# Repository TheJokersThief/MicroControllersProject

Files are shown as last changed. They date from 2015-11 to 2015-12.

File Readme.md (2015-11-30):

# Burglar Alarm Arduino Project
**Task:** Build a burglar alarm — The task for the project was to build a device, using an arduino, that could monitor several different types of zones, log alarm trips and allow for user and admin interaction via an LCD. When an alarm condition is met, a buzzer or LED will go off indicating as such.

## Authors
1. **Evan Smith**
	* [iamevan.me](http://iamevan.me)
	* [@TheJokersThief](http://twitter.com/thejokersthief)
	* [evan.netsoc.co](http://evan.netsoc.co)
2. **Colm Cahalane**
	* [colm.cf](http://colm.cf)
	* [@1108oo](http://twitter.com/1108oo)
	* [colm.netsoc.co](http://colm.netsoc.co)

## Limitations
* 512MB permanent memory for logging and settings storage 
* Only the admin is allowed to change settings
 	
## Features
* The date and time is displayed by default on the LCD 
* There are 4 zones hooked up to the alarm:
	1. Entry/Exit: This is linked to the front door. When tripped, it allows a certain amount of time to disable the alarm before it starts ringing.
	2. Digital: This would be linked to sensors attached to the windows or other vulnerable aspects of the house. When contact is broken, it sets off the alarm. E.G. If a burglar broke in by prying open the window.
	3. Analog: Connected to analog sensors such as a thermometer for detecting heat or variable motion sensors. This is tripped after the sensor signal breaches a certain threshold.
	4. Continuous Monitoring: This alarm is tripped when the signal transitions from high to low, used primarily to ensure no tampering occurs with the burglar alarm.
* A number of zones are programmable and administrators can set a variety of options like: – User password
	* Admin password
	* Do-not-disturb times for the entry/exit zone – Digital zone trip condition
* Whenever a zone is tripped, the event is logged to permanent storage
* Settings, logs, passwords and alarm configuration can be done with an Infra Red Remote

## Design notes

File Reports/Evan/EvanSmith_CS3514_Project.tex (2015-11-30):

%%% Template originaly created by Karol Kozioł (mail@karol-koziol.net) and modified for ShareLaTeX use

\documentclass[a4paper,11pt]{article}

\usepackage[T1]{fontenc}
\usepackage[utf8]{inputenc}
\usepackage{graphicx}
\usepackage{xcolor}

\usepackage{amsmath,amssymb,amsthm,textcomp}
\usepackage{enumerate}
\usepackage{multicol}
\usepackage{tikz}
\usepackage{hyperref}

\usepackage{geometry}
\geometry{total={210mm,297mm},
left=25mm,right=25mm,%
bindingoffset=0mm, top=20mm,bottom=20mm}

\linespread{1.3}

\newcommand{\linia}{\rule{\linewidth}{0.5pt}}

% custom theorems if needed
\newtheoremstyle{mytheor}
    {1ex}{1ex}{\normalfont}{0pt}{\scshape}{.}{1ex}
    {{\thmname{#1 }}{\thmnumber{#2}}{\thmnote{ (#3)}}}

\theoremstyle{mytheor}
\newtheorem{defi}{Definition}

% % my own titles
% \makeatletter
% \renewcommand{\maketitle}{
% \begin{center}
% \vspace{2ex}
% {\huge \textsc{\@title}}
% \vspace{1ex}
% \\
% \linia\\
% \@author \hfill \@date
% \vspace{4ex}
% \end{center}
% }
% \makeatother
% %%%

% custom footers and headers
\usepackage{fancyhdr}
\pagestyle{fancy}
\lhead{}
\chead{}
\rhead{}
\lfoot{CS3514 - Burglar Alarm Project}
\cfoot{}
\rfoot{Page \thepage}
\renewcommand{\headrulewidth}{0pt}
\renewcommand{\footrulewidth}{0pt}
%

% code listing settings
\usepackage{listings}
\lstset{
    language=c,
    basicstyle=\ttfamily\small,
    aboveskip={1.0\baselineskip},
    belowskip={1.0\baselineskip},
    columns=fixed,
    extendedchars=true,
    breaklines=true,
    tabsize=4,
    prebreak=\raisebox{0ex}[0ex][0ex]{\ensuremath{\hookleftarrow}},
    frame=leftline,
    showtabs=false,
    showspaces=false,
    showstringspaces=false,
    keywordstyle=\color[rgb]{0.627,0.126,0.941},
    commentstyle=\color[rgb]{0.133,0.545,0.133},
    stringstyle=\color[rgb]{0.60,0,0},
    numbers=left,
    numberstyle=\small,
    stepnumber=1,
    numbersep=10pt,
    captionpos=t,
    escapeinside={},
    morekeywords={sudo, su, apt-get},
    prebreak= \space,
    postbreak   = \space
}

\hypersetup{%
  colorlinks=true,% hyperlinks will be coloured
  linkcolor=black,% hyperlink text will be green
  linkbordercolor=red,% hyperlink border will be red
}

\usepackage{parskip}

% COLOURS %
\definecolor{inlinebackground}{RGB}{252, 252, 252}

% COMMANDS %
\newcommand{\inlinecode}[1]{\colorbox{inlinebackground}{\lstinline[basicstyle=\ttfamily\color{black}]|#1|}}

%%%----------%%%----------%%%----------%%%----------%%%

\begin{document}

\title{CS3514 - Burglar Alarm Project}

\author{Evan Smith <113300626> and Colm Cahalane}

\date{19/11/2015}

\maketitle

\tableofcontents
\newpage

\section{Introduction}
\textbf{Build a burglar alarm }--- The task for the project was to build a device, using an arduino, that could monitor several different types of zones, log alarm trips and allow for user and admin interaction via an LCD. When an alarm condition is met, a buzzer or LED will go off indicating as such.

\section{Requirements / Analysis / Design }
\subsection{Limitations}
\begin{itemize}
    \item 512MB permanent memory for logging and settings storage
    \item Only the admin is allowed to change settings
\end{itemize}

\subsection{Features}
\begin{itemize}
    \item The date and time is displayed by default on the LCD 
    \item There are 4 zones hooked up to the alarm:
    \begin{enumerate}
        \item \textbf{Entry/Exit:} This is linked to the front door. When tripped, it allows a certain amount of time to disable the alarm before it starts ringing.
        \item \textbf{Digital:} This would be linked to sensors attached to the windows or other vulnerable aspects of the house. When contact is broken, it sets off the alarm. E.G. If a burglar broke in by prying open the window.
        \item \textbf{Analog:} Connected to analog sensors such as a thermometer for detecting heat or variable motion sensors. This is tripped after the sensor signal breaches a certain threshold.
        \item \textbf{Continuous Monitoring:} This alarm is tripped when the signal transitions from high to low, used primarily to ensure no tampering occurs with the burglar alarm.
    \end{enumerate}
    \item A number of zones are programmable and administrators can set a variety of options like:
    \begin{itemize}
        \item User password
        \item Admin password
        \item Do-not-disturb times for the entry/exit zone
        \item Digital zone trip condition
    \end{itemize}
    \item Whenever a zone is tripped, the event is logged to permanent storage
    \item Settings, logs, passwords and alarm configuration can be done with an Infra Red Remote
\end{itemize}

\newpage
\section{Implementation}

\subsection{Flow chart}
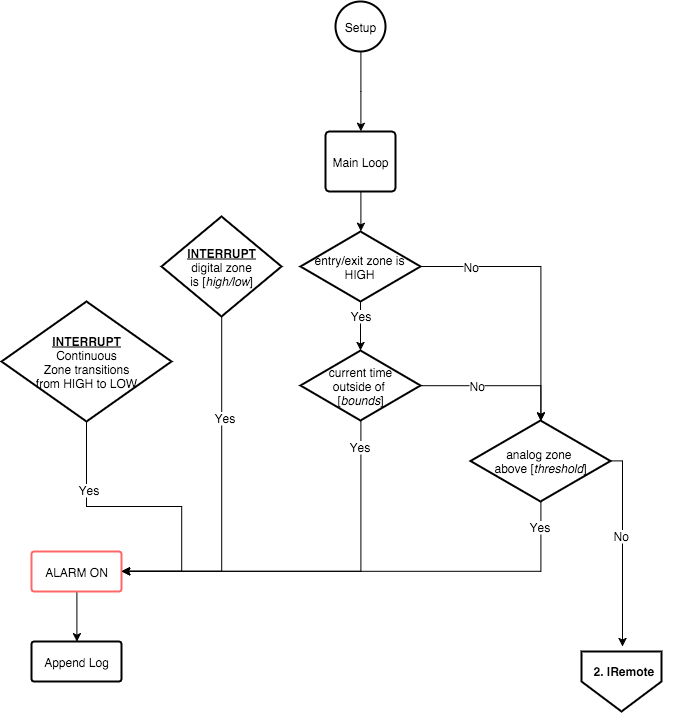
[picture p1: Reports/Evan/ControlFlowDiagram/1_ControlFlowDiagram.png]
\makebox[\textwidth]{}
\newpage
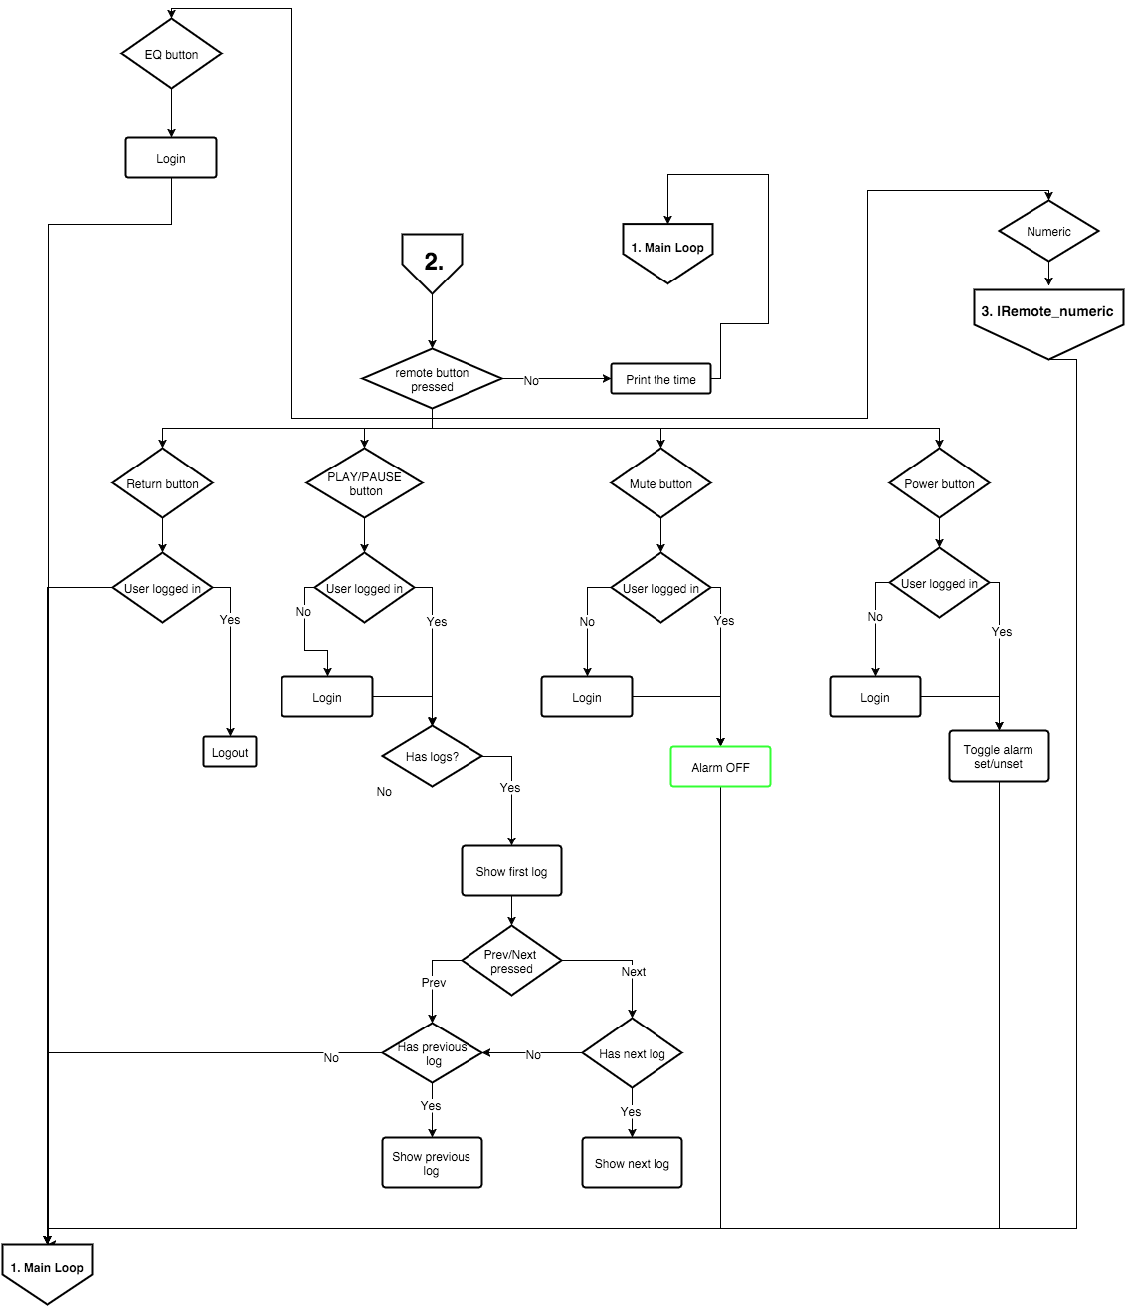
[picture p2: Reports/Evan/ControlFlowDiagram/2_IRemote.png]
\makebox[\textwidth]{}
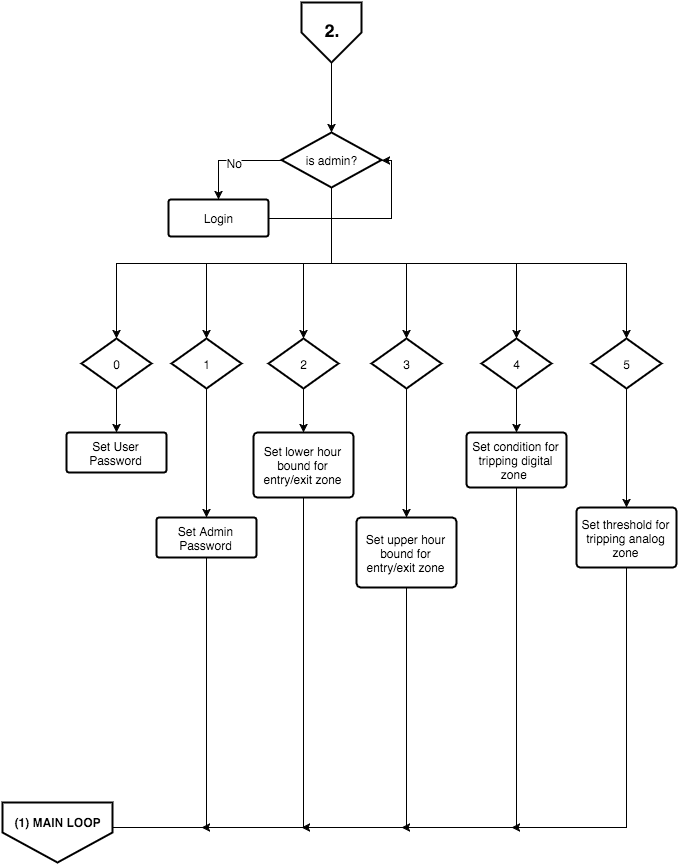
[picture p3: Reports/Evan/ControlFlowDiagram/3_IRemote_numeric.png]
\makebox[\textwidth]{}

\subsection{Circuit Diagram}
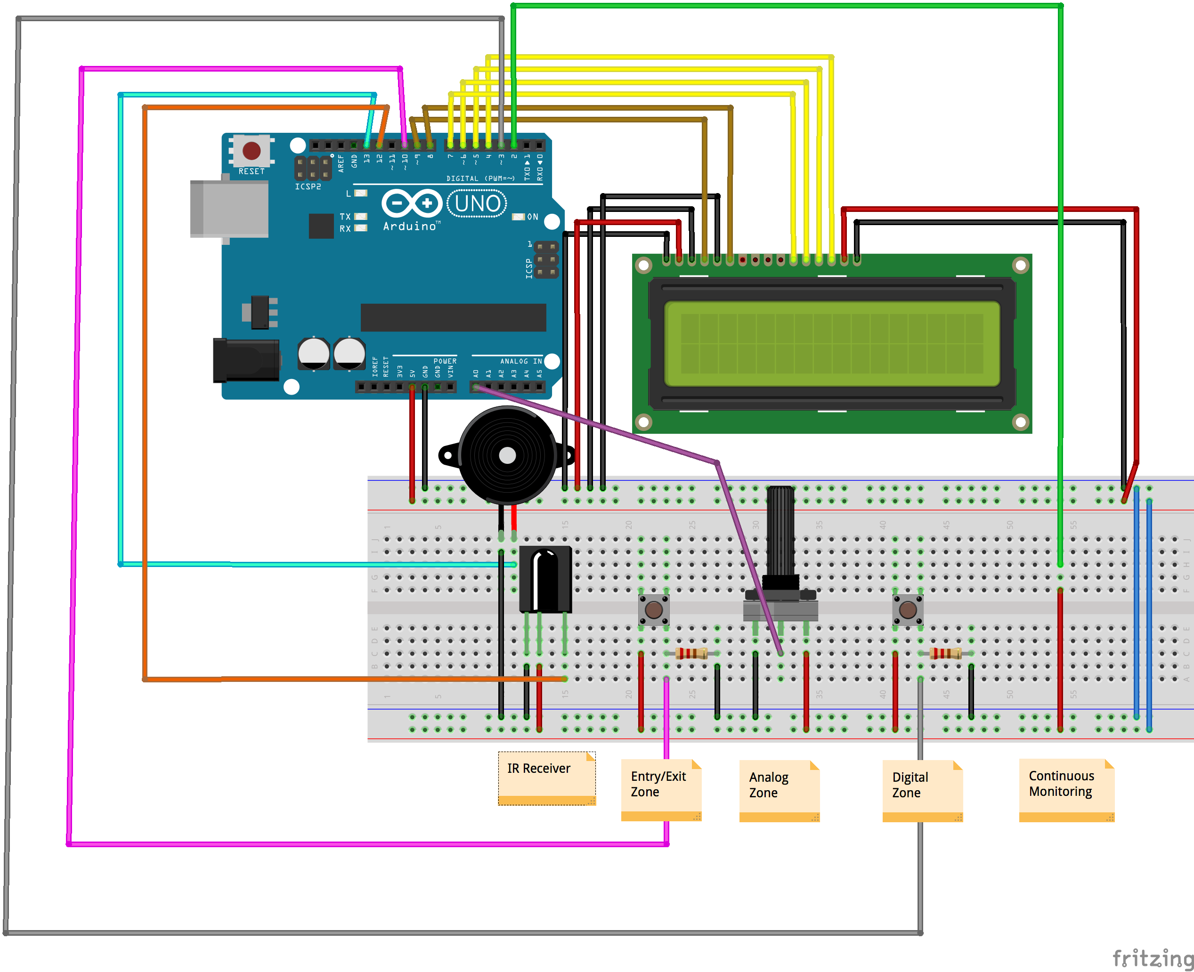
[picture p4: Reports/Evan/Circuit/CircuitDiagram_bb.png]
\makebox[\textwidth]{}

\subsection{Coding decisions}

\subsubsection{Global Variables}
We decided to have five global variables:

\begin{lstlisting}
// initialize the library with the numbers of the interface pins
LiquidCrystal lcd(9, 8, 7, 6, 5, 4);

// Used to check if current user is an admin
unsigned short is_admin = 0;

// 0 is disabled ; 1 is enabled
unsigned short alarm_set = 0;

// 0 alarm is idle ; 1 alarm is ringing
// Volatile because needed in interrupts
volatile unsigned short alarm_active = 0;

// 0 not logged in ; 1 logged in 
unsigned short is_user_logged_in = 0;
\end{lstlisting}

All of these variables are used extensively within other functions for manipulation of the components overall, which is the reason they've been globalised.

\subsubsection{Debouncing IR}

At many points in our code, we add a delay after receiving a numeric signal from the IR Remote in order to prevent extraneous zeroes corrupting the intended number.

\subsubsection{Default Settings on First Time}

When the microcontroller is first setup, we should populate the EEPROM with default settings. Depending on the use of the microcontroller before this program was uploaded, the EEPROM may have old values still stored in its memory so we chose a sentinel value - a 3-byte char - to tell whether the defaults had been set or not. 

\subsubsection{Digital and Continuous Zones are interrupts}

We chose to make the digital and continuous zones as interrupts to simplify the code and make the alarm more responsive.

The continuous zone interrupts on a falling signal only so when the signal goes from HIGH to LOW, the alarm is set off as the wire connection has been broken.

The digital zone interrupts whenever the signal changes and then checks it against the user-defined condition. If the condition is met, the alarm goes off.

\begin{lstlisting}
attachInterrupt( digitalPinToInterrupt(DIGITAL_ZONE_PIN), digitalZoneTrip, CHANGE  );
attachInterrupt( digitalPinToInterrupt(CONTINUOUS_ZONE_PIN), contZoneTrip, FALLING );
\end{lstlisting}

\subsubsection{Check For Admin}
\begin{lstlisting}
if( is_admin || ( loginMode( ) && is_admin ) )
\end{lstlisting}

Whenever we needed an admin login to change settings, etc., we used the fact that C lazy-evaluates to our advantage. If the admin was already logged in, he passed into the statement immediately but if we had to make them login, we used the fact that C evaluates logic conditions from left to right. So first the admin would login and if they were successful, then the \inlinecode{is_admin} flag would be set and we could let them in.

\subsubsection{Logs Loop}

\begin{lstlisting}
int memory_address = LOG_MEMORY_START + (( LOG_MEMORY_START + (LOG_LENGTH * number_of_breaches) ) % 500);
\end{lstlisting}

When storing a log, if we've reached the maximum space (in this case it's 500 bytes to be safe), we loop around and continue writing logs at the beginning of the memory.

\subsubsection{Increased Extensibility for Logging}
\begin{lstlisting}
EEPROM.put( memory_address, time_of_breach );
memory_address += sizeof(time_of_breach);
EEPROM.put( memory_address, (short) zone );
\end{lstlisting}

By using sizeof, we don't have to store a constant with the size of the time variable so we could easily increase the \inlinecode{LOG_LENGTH} constant, add the size of the \inlinecode{zone} variable to the memory address and then write a new variable/value as part of the log.

\section{Evaluation}
\subsection{How successful was it?}
The burglar alarm works as expected but the continuous zone was hard to conceptually understand. We chose a more low-tech, physical approach which achieved the same outcome but was probably not what was sought.

The EEPROM works exceptionally well and leaves a lot of room for additional settings if needed later. 

The analog zone works exactly as expected with the potentiometer as an example.

Attaching the digital and continuous zone to interrupts simplified our code and gives a much more instantaneous response to actions.

The entry/exit zone also works quite nicely despite requiring us to poll for it in the loop. The countdown upon entering the house also works a lot better than expected although the count stops while trying to login so you could theoretically enter login multiple times to keep the alarm occupied while you disabled it.

\subsection{Any improvements?}
We spent a portion of the project misunderstanding that both short and int occupy the same number of bytes, I would probably stick solely to using int data types now knowing this.

Now understanding the role of the continuous monitoring zone more closely, I would probably look at embedding software and circuity in other zones to ensure they're operating as expected instead of our proposed approach.

I would probably create an interrupt for timing so that we could continue to count time as someone's trying to login to the entry/exit zone. I would also set the alarm off on a failed login to avoid a brute force attack.

Logs loop but start muddying the order. We could probably fix this by also storing a sequence number and navigating through them that way.

Because so many of our settings (EG: Digital condition and the upper/lower bound hours) only needed less than 1 byte for storage but took up 2 bytes as ints, we could probably use a single int to store two settings.
\section{Appendices}
\begin{lstlisting}

\end{lstlisting}

\subsection{User manual}
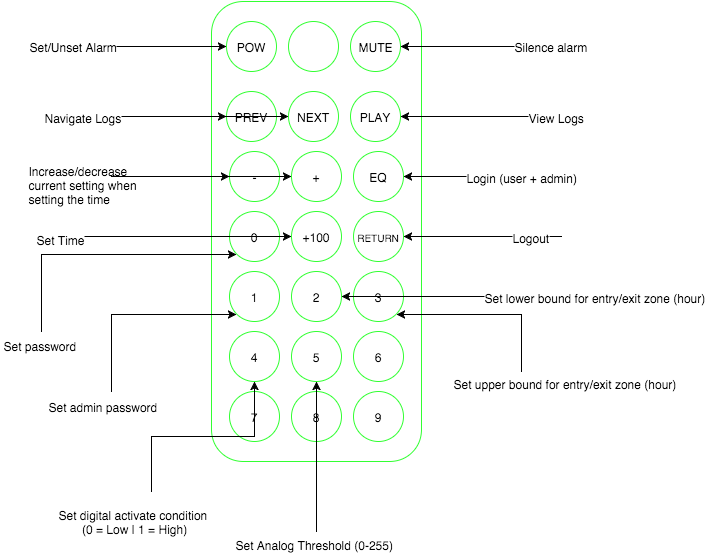
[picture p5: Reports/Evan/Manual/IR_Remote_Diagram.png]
\makebox[\textwidth]{}

\subsubsection{How do I silence the alarm?}
When the alarm is active/sounding, you can silence it using the "Mute" button in the top-right corner of the remote. You will be asked to login (enter your passcode) to deactivate it unless you have recently logged in (\textit{and have not SET the alarm}).

\subsubsection{When will the alarm activate?}
\begin{itemize}
    \item \textbf{Analog Zone:} When the desired threshold is exceeded, the alarm will activate.
    \item \textbf{Digital Zone:} When the chosen condition is met (HIGH/LOW), the alarm will activate.
    \item \textbf{Entry/Exit Zone:} When you enter the house, you will be given 20 seconds to login and deactivate the alarm. The alarm \textbf{will not} activate if you enter your home between the two hours you've selected in the options.
    \item \textbf{Continuous Zone:} When the seal of the box is broken, the two wires connected to the lid of the container will separate and the alarm will sound. This is an anti-tampering measure as the user should never be altering the direct wiring of the alarm after setup.
\end{itemize}

Whenever a zone is tripped, a log of the zone, the date and the time is written to memory for you to browse later. To view logs, hit the play/pause button and use the prev and next buttons to navigate through them.

\subsection{Project plan}
\begin{enumerate}
    \item Map out the EEPROM memory
    \item Assign functions to IR Remote buttons
    \item Map all necessary pins to relevant components
    \item Declare constants at the top of the code
    \item Begin outlining the code
    \item Assemble the hardware for testing
    \item Test, re-iterate
    \item Finalise the code and hardware and test again
\end{enumerate}

Throughout the project, we used Github to organise our code and traded the arduino back and forth as we tackled separate hardware problems and ideas.

\subsubsection{EEPROM Mapping}
\begin{lstlisting}
/**
 * EEPROM Mapping
 * --------------
 * 0 - 1 : password (unsigned int)
 * 2 - 3 : admin password (unsigned int)
 * 4 - 5 : number of breaches (unsigned short)
 * 6 - 8 : first-time settings ("set" or anything else)
 *
 *  Entry/Exit (Zone 0)
 *    15     : lower-bound hour (unsigned short)
 *    16     : upper-bound hour (unsigned short)
 *
 *  Digital (Zone 1)
 *    20    : trip condition (unsigned short)
 *    
 *  Analog  (Zone 2)
 *    30 - 32 : threshold (unsigned int)
 *
 * 100 - 511 : Logging
 *   Bit Mapping (6 bytes each):
 *   0 - 3 : time (unsigned long int)
 *   4 - 5 : zone (unsigned short)
 *   
 */
\end{lstlisting}

\subsubsection{IR Button Mapping}
\begin{lstlisting}
/**
 * IR Remote Layout
 * ----------------
 *
 * EQ : Enter password (4-Digit Pin)
 * Return : Return to standard menu
 * Play/Pause : Navigate Log
 *   Next     : Next log
 *   Prev     : Previous log
 * Mute       : Turn off alarm
 * Power      : Set/unset the alarm
 * 0  : Set user password
 * 1  : Set admin password
 * 2  : Set lower bound hour for entry/exit zone
 * 3  : Set upper bound hour for entry/exit zone
 * 4  : Set digital activate condition
 * 5  : Set analog threshold
 */
\end{lstlisting}

\subsubsection{Pin Mapping}
\begin{lstlisting}
/**
 * Digital
 * -------
 * 
 * 2 (interrupt) : Continuous Zone 
 * 3 (interrupt) : Digital Zone
 * 4 : LCD Screen 
 * 5 : LCD Screen
 * 6 : LCD Screen
 * 7 : LCD Screen
 * 8 : LCD Screen
 * 9 : LCD Screen
 * 10: Entry/Exit Zone
 * 12: IR Sensor
 * 13: ALARM
 * 
 * Analog
 * ------
 * 0 : Analog Zone 1
 */
\end{lstlisting}

\section{Code}

\begin{lstlisting}
#include <EEPROM.h>
#include <Time.h>  
#include <IRremote.h>
#include <LiquidCrystal.h>

/**
 * @author Colm Cahalane
 * @author Evan Smith <113300626>
 *
 * Build a burglar alarm --- The task for the project 
 * was to build a device, using an arduino, that could 
 * monitor several different types of zones, log alarm
 * trips and allow for user and admin interaction via 
 * an LCD. When an alarm condition is met, a buzzer 
 * or LED will go off indicating as such.
 * 
 * Pins
 * ====
 * 
 * Digital
 * -------
 * 
 * 2 (interrupt) : Continuous Zone 
 * 3 (interrupt) : Digital Zone
 * 4 : LCD Screen 
 * 5 : LCD Screen
 * 6 : LCD Screen
 * 7 : LCD Screen
 * 8 : LCD Screen
 * 9 : LCD Screen
 * 10: Entry/Exit Zone
 * 12: IR Sensor
 * 13: ALARM
 * 
 * Analog
 * ------
 * 0 : Analog Zone 1
 *
 * IR Remote Layout
 * ----------------
 *
 * EQ : Enter password (4-Digit Pin)
 * Return : Return to standard menu
 * Play/Pause : Navigate Log
 *   Next     : Next log
 *   Prev     : Previous log
 * Mute       : Turn off alarm
 * Power      : Set/unset the alarm
 * 0  : Set user password
 * 1  : Set admin password
 * 2  : Set lower bound hour for entry/exit zone
 * 3  : Set upper bound hour for entry/exit zone
 * 4  : Set digital activate condition
 * 5  : Set analog threshold
 *
 * EEPROM Mapping
 * --------------
 * 0 - 1 : password (unsigned int)
 * 2 - 3 : admin password (unsigned int)
 * 4 - 5 : number of breaches (unsigned short)
 * 6 - 8 : first-time settings ("set" or anything else)
 *
 *  Entry/Exit (Zone 0)
 *    15     : lower-bound hour (unsigned short)
 *    16     : upper-bound hour (unsigned short)
 *
 *  Digital (Zone 1)
 *    20    : trip condition (unsigned short)
 *    
 *  Analog  (Zone 2)
 *    30 - 32 : threshold (unsigned int)
 *
 * 100 - 511 : Logging
 *   Bit Mapping (6 bytes each):
 *   0 - 3 : time (unsigned long int)
 *   4 - 5 : zone (unsigned short)
 *   
 *   
 */

#define PASSWORD              0     // 4 digit pin
#define ADMIN_PASSWORD        2     // 4 digit pin
#define NUMBER_OF_BREACHES    4
#define FIRST_TIME_SET        6

// ~~~~~ ENTRY / EXIT ZONE ~~~~~
#define ENTRY_EXIT_ZONE       0
#define ENTRY_EXIT_PIN        10
#define LOWER_TIME_BOUND      15     // Hour (2 digits max)
#define UPPER_TIME_BOUND      16     // Hour (2 digits max)

// ~~~~~~~ DIGITAL ZONE ~~~~~~~~
#define DIGITAL_ZONE          1
#define DIGITAL_CONDITION     20    // HIGH (1) or LOW (0)
#define DIGITAL_ZONE_PIN      3

 // ~~~~~~~ ANALOG ZONE ~~~~~~~~
#define ANALOG_ZONE           2
#define ANALOG_THRESHOLD      30    // short between 0 - 255
#define ANALOG_ZONE_PIN       0

 // ~~~ CONTINUOUS MON ZONE ~~~~
#define CONTINUOUS_ZONE       3
#define CONTINUOUS_ZONE_PIN   2

 // ~~~~~ TIME SETTING MODE ~~~~
#define HOUR 0
#define MINUTE 1
#define DAY 2
#define MONTH 3
#define YEAR 4

// ~~~~~~~~~ LOGS ~~~~~~~~~~~~~~
#define LOG_MEMORY_START  100
#define LOG_LENGTH        6

// ~~~~~~~~~~ IR ~~~~~~~~~~~~~~~
#define IR_RECV_PIN   12
IRrecv irrecv(IR_RECV_PIN);
decode_results results;

#define ALARM_PIN     13

// initialize the library with the numbers of the interface pins
LiquidCrystal lcd(9, 8, 7, 6, 5, 4);

// Used to check if current user is an admin
unsigned short is_admin = 0;

// 0 is disabled ; 1 is enabled
unsigned short alarm_set = 0;

// 0 alarm is idle ; 1 alarm is ringing
volatile unsigned short alarm_active = 0;

// 0 not logged in ; 1 logged in 
unsigned short is_user_logged_in = 0;

/**
 * Prints the current time to the LCD
 */
void printTime(){
  lcd.setCursor(0, 0);
  convertUnixToReadable(now());
}

/**
 * Pads and prints an integer with 0s
 * @param val Integer to pad
 */
void printWithLeadingZero(int val){
  if(val < 10){
    lcd.print('0');
  }
  lcd.print(val);
}

/**
 * Set the time
 */
void changeTime(){
    TimeElements t;
    time_t newTime;
    breakTime(now(), t);
    
    int settingsMode = 0;
    short exitLoop = 0;

    while( !exitLoop ){
      newTime = makeTime(t);
  
      lcd.clear();
      lcd.setCursor(0,0);

      lcd.print( hour(newTime) );
      lcd.print(':');
      printWithLeadingZero( minute(newTime) );

      lcd.print(' ');

      printWithLeadingZero( day(newTime) );
      lcd.print('/');
      printWithLeadingZero( month(newTime) );
      lcd.print('/');
      lcd.print( year(newTime) );

      lcd.setCursor(0,1);
      
      if(settingsMode == HOUR){
        lcd.print("Setting HOUR");
      } else if(settingsMode == MINUTE){
        lcd.print("Setting MINUTE");
      } else if(settingsMode == DAY){
        lcd.print("Setting DAY");
      } else if(settingsMode == MONTH){
        lcd.print("Setting MONTH");
      } else if(settingsMode == YEAR){
        lcd.print("Setting YEAR");
      }

      irrecv.resume();
      while( !irrecv.decode(&results) ) { /* Wait for input! */ }
      switch(results.value){
                            // +4 should be -1, but here we avoid nevative modulo
        case 0xFF22DD: /* PREV */ settingsMode = (settingsMode+4)%5;       break;
        case 0xFF02FD: /* NEXT */ settingsMode = (settingsMode+1)%5;       break;
        case 0xFFE01F: /*  -  */
            if(settingsMode == HOUR){
              t.Hour--;
            } else if(settingsMode == MINUTE){
              t.Minute--;
            } else if(settingsMode == DAY){
              t.Day--;
            } else if(settingsMode == MONTH){
              t.Month--;
            } else if(settingsMode == YEAR){
              t.Year--;
            }
           break;
        case 0xFFA857: /*  +  */
            if(settingsMode == HOUR){
              t.Hour++;
            } else if(settingsMode == MINUTE){
              t.Minute++;
            } else if(settingsMode == DAY){
              t.Day++;
            } else if(settingsMode == MONTH){
              t.Month++;
            } else if(settingsMode == YEAR){
              t.Year++;
            }
           break;
        case 0xFFB04F: /* RET */ exitLoop = 1; lcd.clear(); break;
      }
    }

    setTime(newTime);
}

int getDigitFromIR(){
  while( 1 ){
    irrecv.resume();
    while( !irrecv.decode(&results) ) { /* Wait for input! */ }
    switch(results.value)
    {
      case 0xFF6897: return 0;
      case 0xFF30CF: return 1;
      case 0xFF18E7: return 2;
      case 0xFF7A85: return 3;
      case 0xFF10EF: return 4;
      case 0xFF38C7: return 5;
      case 0xFF5AA5: return 6;
      case 0xFF42BD: return 7;
      case 0xFF4AB5: return 8;
      case 0xFF52AD: return 9;
      default:       break; // Other button press or undefined; reloop
    }
  }
}

/**
 * Attempt to log in a user, prompting
 *   them for a user or admin password
 * @return 1 if user logged in ; 0 otherwise
 */
int loginMode() {
  lcd.clear();
  lcd.print( "Login Mode");
  if( !is_user_logged_in || !is_admin ){
    // if admin is already logged in, bypass login

    lcd.clear();
    if( is_user_logged_in && !is_admin ){
      lcd.print( "Enter admin pin");
    } else {
      lcd.print( "4 Digit Pin");
    }
    delay(50);
    
    int pin_entered = 0;
    unsigned int password, admin_password;
    EEPROM.get( PASSWORD, password );
    EEPROM.get( ADMIN_PASSWORD, admin_password );

    lcd.setCursor(0, 1);
    for(int i = 0; i < 4; i++){
      int received_value = getDigitFromIR();      
      pin_entered *= 10;
      pin_entered += received_value;
      lcd.print('*');

      // Minor delay to prevent debouncing "0"s
      delay(50);
      irrecv.resume();
    }

    lcd.setCursor(0,1);
    if( !is_user_logged_in && pin_entered == password ){
      is_user_logged_in = 1;
      lcd.print( "LOGGED IN" );
    } else if( pin_entered == admin_password ){
      is_admin = 1;
      is_user_logged_in = 1;
      lcd.print( "LOGGED IN" );
    } else{
      lcd.print( "FAILED LOGIN" );
    }
    delay(1500);
  } else{
    lcd.print("You are admin");
  }
  lcd.clear();
  
  return is_user_logged_in;
}

/**
 * Append log to memory
 * @param time_of_breach Unix timestamp of current time
 * @param zone           Zone number that was breached
 */
void appendLog( unsigned long int time_of_breach, unsigned short zone ){

  unsigned short number_of_breaches;
  EEPROM.get( NUMBER_OF_BREACHES, number_of_breaches );

  // Increase the number of breaches
  number_of_breaches++;
  EEPROM.put( NUMBER_OF_BREACHES, number_of_breaches );

  int memory_address = LOG_MEMORY_START + (( LOG_MEMORY_START + (LOG_LENGTH * number_of_breaches) ) % 500);

  // Write our log to EEPROM
  EEPROM.put( memory_address, time_of_breach );
  memory_address += sizeof(time_of_breach);
  EEPROM.put( memory_address, (short) zone );
}

/**
 * Allows user to navigate the stored log
 * @param current_log The current log to be printed
 */
void printLog( short current_log ){
  unsigned short number_of_breaches;
  EEPROM.get( NUMBER_OF_BREACHES, number_of_breaches );

  if( current_log <= number_of_breaches && current_log != 0){
    // If we have a log to show 
    int memory_address = LOG_MEMORY_START + (( LOG_MEMORY_START + (LOG_LENGTH * current_log) ) % 500);
    
    unsigned long int time_of_breach;
    unsigned short zone;

    // Get log info
    EEPROM.get( memory_address, time_of_breach );
    memory_address += sizeof(time_of_breach);
    EEPROM.get( memory_address, zone );
    
    lcd.clear();
    switch(zone){
      case DIGITAL_ZONE:
          lcd.print( "DIGITAL ZONE");
        break;
      case ANALOG_ZONE:
          lcd.print("ANALOG ZONE");
        break;
      case CONTINUOUS_ZONE:
          lcd.print( "CONTINUOUS ZONE");
        break;
      case ENTRY_EXIT_ZONE:
          lcd.print("ENTRY/EXIT ZONE");
        break;
      default:
          lcd.print( "UNKNOWN ZONE" );
        break;
    }
    lcd.setCursor(0,1);
    convertUnixToReadable( time_of_breach );

    irrecv.resume();
    while( !irrecv.decode(&results) ) { /* Wait for input! */ }
    switch(results.value)
    {
      case 0xFF22DD: printLog( current_log - 1 );    break;
      case 0xFF02FD: printLog( current_log + 1 );    break;
      case 0xFFB04F: lcd.clear(); /* If return, just let it go */ break;
      default: printLog(current_log); // Other button press or undefined
    }
    irrecv.resume();
  } else{
    lcd.clear();
    lcd.print("NO LOGS");
    delay( 1000 );

    if( current_log > 0 )
      // If current log isn't 0, send them back a log
      printLog( current_log - 1 );
  }
}

/**
 * Prints out unix time in a human-readable format
 * @param  input_time Unix time input
 */
void convertUnixToReadable( unsigned long int input_time ){
  TimeElements full_time;
  breakTime( input_time, full_time );

  printWithLeadingZero(full_time.Hour);
  lcd.print( ":" );
  printWithLeadingZero(full_time.Minute); 
  lcd.print( " " );
  printWithLeadingZero( full_time.Day );
  lcd.print("/");
  printWithLeadingZero( full_time.Month );
  lcd.print("/");
  lcd.print( full_time.Year + 1970 );
}

/**
 * Exit admin mode
 */
void exitAdmin( ){
  is_admin = 0;
  logout( );
}

/**
 * Remove logged in status
 */
void logout( ){
  is_user_logged_in = 0;
  lcd.clear();
  lcd.print("Logged out");
  delay(700);
}

/**
 * Change whether the alarm can be active or not
 */
void toggleAlarmSet( ){
  if( !alarm_active ){
    lcd.clear();
    // We set the alarm at the end of the function to
    // avoid interrupts triggering the alarm
    unsigned short temp_alarm = !alarm_set;
    
    if( temp_alarm ){
      logout( );
      for (int i = 9; i < 10 && i >= 0; i--){
        lcd.clear();
        lcd.print(i);
        delay(1000);
      }
      lcd.clear();
      lcd.print( "ALARM SET" );
      delay(800);
    } else{
      lcd.print( "ALARM UNSET" );
      delay(800);
    }

    alarm_set = temp_alarm;
  }
}

/**
 * Change whether alarm is ringing or not
 */
void toggleAlarm( ){
  alarm_active = !alarm_active;

  lcd.clear();
  lcd.setCursor(0,1);
  if( alarm_set ){
    if( alarm_active ){
      lcd.print( "ALARM ACTIVE     " );
      digitalWrite( ALARM_PIN, HIGH );
    } else {
      lcd.print( "ALARM DEACTIVATED" );
      digitalWrite( ALARM_PIN, LOW );
      delay(1500);
      lcd.clear();
    }
  }
}

/**
 * Trip the digital zone if conditions are met
 */
void digitalZoneTrip( ){
  volatile unsigned short trip_condition;
  EEPROM.get( DIGITAL_CONDITION, trip_condition );

  if( trip_condition ){
    if( digitalRead( DIGITAL_ZONE_PIN ) == HIGH && !alarm_active && alarm_set ){
      toggleAlarm( );
      appendLog( now(), DIGITAL_ZONE );
    }
  } else {
    if( digitalRead( DIGITAL_ZONE_PIN ) == LOW && !alarm_active && alarm_set ){
      toggleAlarm( );
      appendLog( now(), DIGITAL_ZONE );
    }
  }
}

/**
 * Trip the continuous zone
 */
void contZoneTrip( ){
  toggleAlarm( );
  appendLog( now(), CONTINUOUS_ZONE );
}

/**
 * Trip the analog zone if higher than threshold
 */
void analogZoneTrip( ){
  unsigned int threshold;
  EEPROM.get( ANALOG_THRESHOLD, threshold );

  if( analogRead( ANALOG_ZONE_PIN ) > threshold && !alarm_active && alarm_set ){
    toggleAlarm( );
    appendLog( now(), ANALOG_ZONE );
    delay(200);
  }
}

/**
 * Allows users to set permanent option 
 *   values (stored in EEPROM)
 * @param option Option number from IR Remote
 */
void setOption( short option ){
  unsigned int address;
  unsigned short digits;
  switch( option ){
    case 0:
        lcd.print("PASSWORD");
        address = PASSWORD;
        digits = 4;
      break;
    case 1:
        lcd.print("ADMIN_PASSWORD");
        address = ADMIN_PASSWORD;
        digits = 4;
      break;
    case 2:
        lcd.print("LOWER TIME (Hour)");
        address = LOWER_TIME_BOUND;
        digits = 2;
      break;
    case 3:
        lcd.print("UPPER TIME (Hour)");
        address = UPPER_TIME_BOUND;
        digits = 2;
      break;
    case 4:
        lcd.print("DIGITAL COND 0/1");
        address = DIGITAL_CONDITION;
        digits = 1;
      break;
    case 5:
        lcd.print("ANALOG THRESH 1-255");
        address = ANALOG_THRESHOLD;
        digits = 3;
      break;
    default:
        return;
      break;
  }

  if( digits > 2 ){
    // If there are more than 2 digits, we'll need an int
    unsigned int final_value = 0;
    lcd.setCursor(0,1);
    for(int i = 0; i < digits; i++){
      int received_value = getDigitFromIR();
        final_value *= 10;
        final_value += received_value;
        lcd.print(received_value);
        // Minor delay to prevent debouncing "0"s
        delay(50);
        irrecv.resume();
    }
    EEPROM.put( address, final_value );
  } else {
    // If there are less than 2 digits, we can use a short
    unsigned short final_value = 0;
    lcd.setCursor(0,1);
    for(int i = 0; i < digits; i++){
      int received_value = getDigitFromIR();
        final_value *= 10;
        final_value += received_value;
        lcd.print(received_value);
        // Minor delay to prevent debouncing "0"s
        delay(50);
        irrecv.resume();
    }
    EEPROM.put( address, final_value );
  }
}

/**
 * Places default values in memory if it's the 
 * first time
 */
void defaults(){
  unsigned int password = 1234, 
               admin_password = 5678, 
               analog_threshold = 100;

  unsigned short number_breaches = 0,
                 lower_bound_hour = 20,
                 upper_bound_hour = 22,
                 digital_trip_condition = 1;

  char first_time[] = "SET";
  EEPROM.put( FIRST_TIME_SET, first_time );
  EEPROM.put( PASSWORD, password );
  EEPROM.put( ADMIN_PASSWORD, admin_password );
  EEPROM.put( ANALOG_THRESHOLD, analog_threshold );

  EEPROM.put( NUMBER_OF_BREACHES, number_breaches );
  EEPROM.put( LOWER_TIME_BOUND, lower_bound_hour );
  EEPROM.put( UPPER_TIME_BOUND, upper_bound_hour );
  EEPROM.put( DIGITAL_CONDITION, digital_trip_condition );
}

/**
 * Check if settings exist
 * @return 0 if not first time; 1 if first time
 */
int settingsSet( ){
  char first_time[3];

  EEPROM.get( FIRST_TIME_SET, first_time );

  return !(first_time == "SET");
}

void setup() {
  Serial.begin(9600);

  pinMode(ALARM_PIN, OUTPUT);
  pinMode(CONTINUOUS_ZONE_PIN, INPUT);
  pinMode(DIGITAL_ZONE_PIN, INPUT);
  pinMode(ENTRY_EXIT_PIN, INPUT);

  digitalWrite( ALARM_PIN, LOW );
  digitalWrite( CONTINUOUS_ZONE_PIN, LOW );
  digitalWrite( DIGITAL_ZONE_PIN, LOW );

  attachInterrupt( digitalPinToInterrupt(DIGITAL_ZONE_PIN), digitalZoneTrip, CHANGE  );
  attachInterrupt( digitalPinToInterrupt(CONTINUOUS_ZONE_PIN), contZoneTrip, FALLING );

  int first_time = settingsSet( );

  if( first_time ){
    defaults();
  }

  alarm_set = 0;
  
  setTime( 1447854337 );
      
  irrecv.enableIRIn(); 

  lcd.begin(16, 2);
}

void loop() {

  /**
   * Trip the Entry/Exit zone as necessary
   */
  if( digitalRead(ENTRY_EXIT_PIN) == HIGH ){
    unsigned short lower, upper, currentHour;
    EEPROM.get( LOWER_TIME_BOUND, lower );
    EEPROM.get( UPPER_TIME_BOUND, upper );
    currentHour = hour();

    lcd.clear();
    lcd.print("Plz login (EQ)");
    long start_time = millis();
    lcd.setCursor(0,1);
    while( (millis() - start_time) < 20000 ){
       
      irrecv.resume();
      delay(300);
      if(irrecv.decode(&results)){  
        if( results.value == 0xFF906F ){
          if( !is_user_logged_in ){
           loginMode( );
          }
          lcd.clear();
          lcd.print("Crisis averted");
          delay(800);
          break;
        }
      }
      lcd.clear();
      lcd.print("Plz login (EQ)");
      lcd.setCursor(0,1);
      lcd.print( 20 - ((millis() - start_time) / 1000) );
    }
    irrecv.resume(); 

    if( !alarm_active && alarm_set && !( currentHour <= lower && currentHour >= upper) ){
      // If current hour is not between the upper and lower bound
      // then activate the alarm
      toggleAlarm( );
      appendLog( now(), ENTRY_EXIT_ZONE );
      delay( 200 );
    }
  }
  
  analogZoneTrip( );

  if( irrecv.decode(&results) ) {
    switch(results.value)
    {
      case 0xFF906F: 
          // EQ
          loginMode();
        break;
      case 0xFFA25D:
          // POW
          if( !alarm_active && ( is_user_logged_in || loginMode() ) )
            toggleAlarmSet( );
        break;
      case 0xFFE21D:
          // MUTE
          if( alarm_active && ( is_user_logged_in || loginMode() ) ){
            toggleAlarm();
          }
        break;
      case 0xFFC23D: 
          /* PLAY/PAUSE */ 
          if( is_user_logged_in || loginMode() )
            printLog( 1 ); 
        break;
      case 0xFF9867:
          /* 100+ */
          if(is_user_logged_in || loginMode() ){
            changeTime();
          }
        break;

      case 0xFFB04F:
          // RET
          if( is_admin ){
            exitAdmin( );
          } else if( is_user_logged_in ){
            logout();
          }
        break;

      /* SET OPTION VALUES */
      case 0xFF6897: 
          if( is_admin || ( loginMode( ) && is_admin ) )
            setOption( 0 );
        break;
      case 0xFF30CF: 
          if( is_admin || ( loginMode( ) && is_admin ) )
            setOption( 1 );
        break;
      case 0xFF18E7: 
          if( is_admin || ( loginMode( ) && is_admin ) )
            setOption( 2 );
        break;
      case 0xFFFFFF: 
          if( is_admin || ( loginMode( ) && is_admin ) )
            setOption( 3 );
        break;
      case 0xFF10EF: 
          if( is_admin || ( loginMode( ) && is_admin ) )
            setOption( 4 );
        break;
      case 0xFF38C7: 
          if( is_admin || ( loginMode( ) && is_admin ) )
            setOption( 5 );
        break;

      default: Serial.println("unrecognised");
    }

    irrecv.resume(); // Receive the next value
  } else {
      printTime();
  }

}
\end{lstlisting}

\end{document}

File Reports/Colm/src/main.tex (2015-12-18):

%%% Template originaly created by Karol Kozioł (mail@karol-koziol.net) and modified for ShareLaTeX use

\documentclass[a4paper,11pt]{article}

\usepackage[utf8]{inputenc}
\usepackage{graphicx}
\usepackage{xcolor}

\renewcommand\familydefault{\sfdefault}

\usepackage{amsmath,amssymb,amsthm,textcomp}
\usepackage{enumerate}
\usepackage{multicol}
\usepackage{tikz}
\usepackage{hyperref}

\usepackage{geometry}
\geometry{total={210mm,297mm},
left=25mm,right=25mm,%
bindingoffset=0mm, top=20mm,bottom=20mm}

\linespread{1.3}

\newcommand{\linia}{\rule{\linewidth}{0.5pt}}

% custom theorems if needed
\newtheoremstyle{mytheor}
    {1ex}{1ex}{cmr}{0pt}{\scshape}{.}{1ex}
    {{\thmname{#1 }}{\thmnumber{#2}}{\thmnote{ (#3)}}}

\theoremstyle{mytheor}
\newtheorem{defi}{Definition}

% my own titles
\makeatletter
\renewcommand{\maketitle}{
\begin{center}
\vspace{2ex}
{\huge \textsc{\@title}}
\vspace{1ex}
\\
\linia\\
\@author \hfill \@date
\vspace{4ex}
\end{center}
}
\makeatother
%%%

% custom footers and headers
\usepackage{fancyhdr}
\pagestyle{fancy}
\lhead{}
\chead{}
\rhead{}
\lfoot{Building a Burglar Alarm with Arduino}
\cfoot{}
\rfoot{Page \thepage}
\renewcommand{\headrulewidth}{0pt}
\renewcommand{\footrulewidth}{0pt}
%

% code listing settings
\usepackage{listings}
\lstset{
    language=c,
    basicstyle=\ttfamily\small,
    aboveskip={1.0\baselineskip},
    belowskip={1.0\baselineskip},
    columns=fixed,
    extendedchars=true,
    breaklines=true,
    tabsize=4,
    prebreak=\raisebox{0ex}[0ex][0ex]{\ensuremath{\hookleftarrow}},
    frame=leftline,
    showtabs=false,
    showspaces=false,
    showstringspaces=false,
    keywordstyle=\color[rgb]{0.627,0.126,0.941},
    commentstyle=\color[rgb]{0.133,0.545,0.133},
    stringstyle=\color[rgb]{0.60,0,0},
    numbers=left,
    numberstyle=\small,
    stepnumber=1,
    numbersep=10pt,
    captionpos=t,
    escapeinside={},
    morekeywords={EEPROM, irrecv, lcd, makeTime, breakTime, time_t, TimeElements, pinMode, digitalWrite, attachInterrupt, setTime, delay, LiquidCrystal, IRrecv, decode_results},
    prebreak= \space,
    postbreak   = \space
}

\hypersetup{%
  colorlinks=true,% hyperlinks will be coloured
  linkcolor=black,% hyperlink text will be green
  linkbordercolor=red,% hyperlink border will be red
}

\usepackage{parskip}

% COLOURS %
\definecolor{inlinebackground}{RGB}{252, 252, 252}

% COMMANDS %
\newcommand{\inlinecode}[1]{\colorbox{inlinebackground}{\lstinline[basicstyle=\ttfamily\color{black}]|#1|}}

%%%----------%%%----------%%%----------%%%----------%%%

\begin{document}

\title{CS3514 C Programming for Microcontrollers Report}

\author{Colm Cahalane}

\date{28/11/2015}

\maketitle

\tableofcontents
\newpage

\section{Introduction}

The goal of this project was to construct a burglar alarm with some basic functionality using C and the Arduino framework for microcontrollers.

Some basic restrictions and requirements that were to be placed on the project were:

\begin{itemize}
\item The burglar alarm should be standalone and shouldn't need a computer to run.
\item The burglar alarm should have a settable clock with date and time.
\item The burglar alarm must support multiple zones:
\begin{itemize}
\item A digital zone, which can be active on high or low.
\item An analog zone, with a variable threshold that can be set by user.
\item An entry-exit zone that allows a user to enter a PIN number and not set off the alarm - or allow a user to arm the system and exit during a grace period.
\item A continuous monitoring zone that triggers on the high → low transition.
\end{itemize}
\item The burglar alarm must have a number of persistent settings stored in memory.
\item The burglar alarm should have a basic PIN login system.
\begin{itemize}
\item There should be a separate administrator level for making settings.
\end{itemize}
\item The burglar alarm should have the ability to store logs in EEPROM. A registered administrator should be able to view these logs on screen.
\end{itemize}

We were given a basic Arduino Duemilanove kit with which to construct the project which included an IR Remote and receiver, 2x16 character LCD Display, buttons to use as triggers, a potentiometer for analogue input, some LED lights and buzzers, a breadboard and a collection of wires.
\newpage
\section{Requirements\textbackslash Analysis\textbackslash Design}

\subsection{What are we building?}

As our group interpreted the project specifications, hardware-wise, we're looking to build a device that relays sensors for the four zones and a receiver for the IR remote to the Arduino.

The digital zones and entry-exit zones here will be activated by buttons, as that's the most simple implementation of such. Ideally, we'd like to have some sort of IR sensor for the entry-exit zone, but this is complicated by our use of IR for the remote.

The Continuous Monitoring Zone behaves like a sort of anti-tamper device; it's attached directly to a source of 5V. If the connection is broken and a high → low transition occurs on this signal, an interrupt should be triggered in software.

In return, output is to be handled by a single-pin output for a buzzer or LED and a more detailed output through the LCD display.

Ideally, for digital inputs, it would be best that we could implement these as triggering interrupts.

The goal of the project is that a user can interface with the alarm's options and settings clearly using the LCD and remote, so inputs and outputs related to operating the device should be kept very simple.

Most of the alarm's other functionality, such as timekeeping, permanent storage etc. can be implemented purely in software.

In the below table and figure we'll describe the hardware implementation and design we settled on as a group.

\begin{figure}[h]
\caption{A diagram, generated using Fritzing, that shows the hardware design we decided on.}
\centering
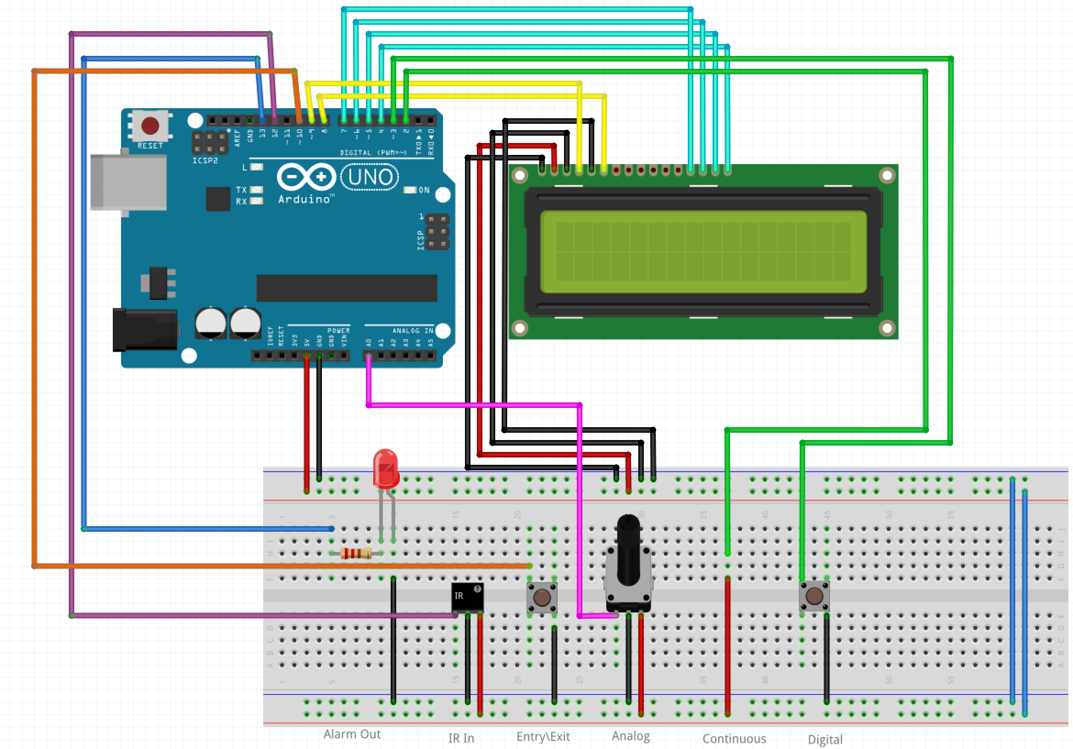
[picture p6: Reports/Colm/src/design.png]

\end{figure}

\begin{table}[h]
\centering
\caption{A list of the Arduino's pins in use, and how we're using them.}
\label{Pins}
\begin{tabular}{lll}
Pin \# & Mode                   & Function              \\
2      & Input (Interrupt)      & Continuous Monitoring \\
3      & Input (Interrupt)      & Digital Zone          \\
4      & Output (LiquidCrystal) & LCD                   \\
5      & Output (LiquidCrystal) & LCD                   \\
6      & Output (LiquidCrystal) & LCD                   \\
7      & Output (LiquidCrystal) & LCD                   \\
8      & Output (LiquidCrystal) & LCD                   \\
9      & Output (LiquidCrystal) & LCD                   \\
10     & Input                  & Entry/Exit Zone       \\
12     & Input (IRRemote)       & IR Sensor             \\
13     & Output                 & Alarm Output          \\
A0     & Analog Input           & Analog Zone          
\end{tabular}
\end{table}

\newpage

\subsection{What are the features we're building?}
We'll need to build software that monitors and responds to the aforementioned zones.

As indicated in the introduction, we're looking to build a number of useful features on top of the hardware that we've designed. We'll need to be able to have user login and verification, two different passwords (one for admin and one for "normal" user).

We'll need an implementation of a clock and allow the user to set the time. Timekeeping is important for our implementation of the entry/exit zone as it has certain specific hours of activity each day as well as 

We'll need a way to implement user settings and make sure that defaults are working in a way that makes sense.

The settings that we'll need to implement are:
\begin{itemize}
\item User Password
\item Admin Password
\item Threshold for Analog Zone (0 - 1024)
\item Active Hours for Entry\textbackslash Exit zone
\item Digital Zone - active high or active low
\end{itemize}

We'll need to develop a simple user privileges system and login mode to ensure that these settings are protected. Also, we shouldn't allow the alarm to be unset or disarmed until a valid login has occurred.

If any of the zone conditions are triggered, an alarm should start sounding and only be disabled if a logged-in user silences it. When an alarm sounds, we want there to be a record of this stored in permanent storage.

We'll also want these logs to be viewable by a logged-in user.

\subsection{What are the limitations we'll face?}

\subsubsection{16x2 Screen}
The 16x2 screen, allowing for 32 characters on screen at any time and of which one row is generally used for the clock, means that the user experience must suffer for functionality; we weren't able to provide for a full user menu and navigation experience. In the software design we've built commands must be learnt off or read from a manual. This is less than ideal.

\subsubsection{Timekeeping}
The Arduino doesn't have much functionality for timekeeping built in that would work in a way that suits us. While we can keep count of the number of milliseconds since the Arduino was started using {\fontfamily{cmtt}\selectfont millis()}, this doesn't work within interrupts and is not an adequate solution to implement a settable clock.

We'd have to implement a clock ourselves through a carefully written interrupt, or we could use the {\fontfamily{cmtt}\selectfont Time.h} library.

\subsubsection{Limited number of interruptable pins}
Though it would suit us to have all digital inputs handled as interrupts, the Arduino Duemilanove board only allows pins 2 and 3 to trigger interrupts. As such, we can't attach an interrupt to each of the digital, entry-exit and continuous monitoring zones. We must choose these carefully.

\subsubsection{EEPROM}
Permanent storage on an Arduino board is here provided by a library which allows for writing from and reading to EEPROM storage based on addresses. It is therefore important to us to divide the space available into EEPROM into blocks and designate specific addresses to specific functions. We must also make sure that at the same time that we have a way of checking that the values in EEPROM are set, and if not, imposing some defaults so that invalid information is not placed into the program.

\subsection{Dividing program into functional blocks.}
Based on this description of the software, we need to start to break down the program into functional blocks.

\begin{itemize}
\item A setup function that runs when the Arduino is first turned on.
\item A function which runs to check if the settings stored in EEPROM are valid and if not, set defaults.
\item Interrupt service routines for when the digital or continuous zones are breached.
\item The program's main execution loop.
\begin{itemize}
\item A section of this loop to poll the entry-exit zone and if it has been tripped, prompts the user to log in during a countdown - otherwise triggers alarm. 
\item A section of this loop to poll the analog zone and trip it if necessary
\item A function allowing a user to log in/out
\item A function allowing a logged in admin to view logs
\item A function that displays a log at an address in EEPROM
\item A function allowing a logged in admin to arm/disarm the alarm
\item A function allowing a logged in user to deactivate an active alarm.
\item A function allowing a logged in admin to set the time
\item A function allowing a logged in admin to change options stored in EEPROM
\item A function which prints the current time.
\end{itemize}
\item A set of functions available to write logs to EEPROM if an alarm is triggered.
\item A set of functions to allow settings in EEPROM to be read and changed.
\item A set of functions to interpret user input from the IR remote and return values.
\end{itemize}

\section{Implementation}

\subsection{Control-Flow Diagram}
\newpage
\begin{figure}[h!]
\caption{A general control-flow diagram layout for the program.}
\centering

\end{figure}
\begin{figure}[h!]
\caption{A control-flow diagram the program's settings stored in EEPROM.}
\centering

\end{figure}
\begin{figure}[h!]
\caption{A control-flow diagram for the program's time settings.}
\centering

\end{figure}

\subsection{Coding Decisions}
\subsubsection{Timekeeping}
As outlined above in the limitations section, we had to make a decision on using a timekeeping library or write our own with interrupts. Our decision was to use {\fontfamily{cmtt}\selectfont Time.h} but the limitations of the Arduino and the small 16x2 screen meant that a user can only set the time by using the + and - buttons to increment and decrement the day/month/hour/minute etc. rather than enter the dates with numeric keys. Still, it makes up for this by giving us a universal date format that we can use in creating/storing logs, and the TimeElements structure for printing/setting time with very readable and maintainable code.

If we were to use the interrupt-based approach, this code would have been used to create a clock-based interrupt which would trigger once per second:
\begin{lstlisting}
  TCCR1A = 0;
  TCCR1B = 0;
  OCR1A = 15625;
  TCCR1B |= (1 << WGM12);
  TCCR1B |= (1 << CS10);
  TCCR1B |= (1 << CS12);
  TIMSK1 |= (1 << OCIE1A);
  sei();
\end{lstlisting}

\subsubsection{EEPROM Mapping and defaults}
We had to map out specific areas of EEPROM and the types of values that could be stored there but it took us a while to come up with a good solution for the first-boot and ensuring that the values in EEPROM were legitimate. We decided on mapping a sequence of addresses that would contain the values 'S', 'E', 'T', allowing us to have a pretty reliable indicator for if the device had been set up with the burglar alarm before. If the SET values aren't present, we'd run a function which would flash defaults.

\begin{table}[]
\centering
\caption{Locations of values stored in EEPROM and their types}
\label{EEPROM Mapping}
\begin{tabular}{lll}
Location & Information                                               & Type                        \\
0-1      & Password                                                  & unsigned int                \\
2-3      & Administrator Password                                    & unsigned int                \\
4-5      & Number Of Breaches                                        & unsigned short              \\
6-8      & 'S' 'E' 'T' values                                        & char{[}{]}                  \\
15       & lower-bound hour for entry/exit zone                      & unsigned short              \\
17       & upper-bound hour for entry/exit zone                      & unsigned short              \\
20       & Trip condition for digital zone (high/low like a boolean) & unsigned short              \\
30-32    & Threshold value for analog zone                           & unsigned int                \\
100-511  & Logging                                                   & 6 byte segments as follows: \\
L0-3     & Time of Breach                                            & unsigned long               \\
L4-5     & Zone ID                                                   & unsigned short             
\end{tabular}
\end{table}

\subsubsection{User Interaction}
As shown in the Control-Flow Diagram, the user can log in to the device, and then enter a number of settings modes from within the main loop. If the user is not logged in and attempts to enter a settings mode, they will be first asked to log in.

Handling most of this user interaction from within the main loop and not constructing an additional menu simply means that we can continue to monitor the analog and entry-exit zones actively as the user interacts with the device.

\subsubsection{Interrupts}
We use both interrupt pins to the board to ensure that active monitoring takes place at all times on certain pins. The continuous zone is set to interrupt on the high → low transition and instantly triggers the alarm. The digital zone is set to interrupt on any change and if the alarm is set, is not currently active and the digital zone switches to the condition specified by the user, the alarm is triggered.

We can not set an interrupt-based system to monitor the analog pin, and the entry-exit zone works better as a non-interrupt due to its tie-ins with the user account system and user interaction functions.

\subsection{Interesting pieces of code}

Here I'm including some particular segments of the codebase for the project that I find rather interesting or valuable in achieving elements of the project specification. Of course, the complete codebase for the project is available in the appendixes.

\subsubsection{Getting a digit value from the IR sensor}
\begin{lstlisting}
int getDigitFromIR(){
  while( 1 ){ // Loop until a button press is received
    irrecv.resume();
    while( !irrecv.decode(&results) ) { /* Wait for input! */ }
    switch(results.value)
    {
      case 0xFF6897: return 0;
      case 0xFF30CF: return 1;
      case 0xFF18E7: return 2;
      case 0xFF7A85: return 3;
      case 0xFF10EF: return 4;
      case 0xFF38C7: return 5;
      case 0xFF5AA5: return 6;
      case 0xFF42BD: return 7;
      case 0xFF4AB5: return 8;
      case 0xFF52AD: return 9;
      default:       break; // Other button press or undefined; reloop
    }
  }
}
\end{lstlisting}

\subsubsection{Checking if the EEPROM is set up right and setting defaults}
\begin{lstlisting}
int settingsSet( ){
  char first_time[3];
  EEPROM.get( FIRST_TIME_SET, first_time );
  
  // Check if the values found match our chosen string.
  return !(first_time == "SET");
}

void defaults(){
  unsigned int password = 1234, 
               admin_password = 5678, 
               analog_threshold = 100;

  unsigned short number_breaches = 0,
                 lower_bound_hour = 20,
                 upper_bound_hour = 22,
                 digital_trip_condition = 1;

  char first_time[] = "SET";
  
  // Store our default values in memory.
  EEPROM.put( FIRST_TIME_SET, first_time );
  EEPROM.put( PASSWORD, password );
  EEPROM.put( ADMIN_PASSWORD, admin_password );
  EEPROM.put( ANALOG_THRESHOLD, analog_threshold );

  EEPROM.put( NUMBER_OF_BREACHES, number_breaches );
  EEPROM.put( LOWER_TIME_BOUND, lower_bound_hour );
  EEPROM.put( UPPER_TIME_BOUND, upper_bound_hour );
  EEPROM.put( DIGITAL_CONDITION, digital_trip_condition );
}
\end{lstlisting}

\subsubsection{Printing UNIX time values}
\begin{lstlisting}
void printWithLeadingZero(int val){
  if(val < 10){
    lcd.print('0');
  }
  lcd.print(val);
}

void convertUnixToReadable( unsigned long int input_time ){
  TimeElements full_time;
  breakTime( input_time, full_time );

  printWithLeadingZero(full_time.Hour);
  lcd.print( ":" );
  printWithLeadingZero(full_time.Minute); 
  lcd.print( " " );
  printWithLeadingZero( full_time.Day );
  lcd.print("/");
  printWithLeadingZero( full_time.Month );
  lcd.print("/");
  lcd.print( full_time.Year + 1970 );
}
\end{lstlisting}

\subsubsection{User interface for modifying time}

\begin{lstlisting}
void changeTime(){
    TimeElements t;
    time_t newTime;
    breakTime(now(), t);
    
    int settingsMode = 0;
    short exitLoop = 0;

    while( !exitLoop ){
      newTime = makeTime(t);
  
      lcd.clear();
      lcd.setCursor(0,0);

      convertUnixToReadable(newTime);
    
      lcd.setCursor(0,1);
      
      if(settingsMode == HOUR){
        lcd.print("Setting HOUR");
      } else if(settingsMode == MINUTE){
        lcd.print("Setting MINUTE");
      } else if(settingsMode == DAY){
        lcd.print("Setting DAY");
      } else if(settingsMode == MONTH){
        lcd.print("Setting MONTH");
      } else if(settingsMode == YEAR){
        lcd.print("Setting YEAR");
      }

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

    setTime(newTime);
}
\end{lstlisting}

\subsubsection{Logging functions}
\begin{lstlisting}
/**
 * Append log to memory
 * @param time_of_breach Unix timestamp of current time
 * @param zone           Zone number that was breached
 */
void appendLog( unsigned long int time_of_breach, unsigned short zone ){

  unsigned short number_of_breaches;
  EEPROM.get( NUMBER_OF_BREACHES, number_of_breaches );

  // Increase the number of breaches
  number_of_breaches++;
  EEPROM.put( NUMBER_OF_BREACHES, number_of_breaches );

  int memory_address = LOG_MEMORY_START + (( LOG_MEMORY_START + (LOG_LENGTH * number_of_breaches) ) % 500);

  // Write our log to EEPROM
  EEPROM.put( memory_address, time_of_breach );
  memory_address += sizeof(time_of_breach);
  EEPROM.put( memory_address, (short) zone );
}

/**
 * Allows user to navigate the stored log
 * @param current_log The current log to be printed
 */
void printLog( short current_log ){
  unsigned short number_of_breaches;
  EEPROM.get( NUMBER_OF_BREACHES, number_of_breaches );

  if( current_log <= number_of_breaches && current_log != 0){
    // If we have a log to show 
    int memory_address = LOG_MEMORY_START + (( LOG_MEMORY_START + (LOG_LENGTH * current_log) ) % 500);
    
    unsigned long int time_of_breach;
    unsigned short zone;

    // Get log info
    EEPROM.get( memory_address, time_of_breach );
    memory_address += sizeof(time_of_breach);
    EEPROM.get( memory_address, zone );
    
    lcd.clear();
    switch(zone){
      case DIGITAL_ZONE:
          lcd.print( "DIGITAL ZONE");
        break;
      case ANALOG_ZONE:
          lcd.print("ANALOG ZONE");
        break;
      case CONTINUOUS_ZONE:
          lcd.print( "CONTINUOUS ZONE");
        break;
      case ENTRY_EXIT_ZONE:
          lcd.print("ENTRY/EXIT ZONE");
        break;
      default:
          lcd.print( "UNKNOWN ZONE" );
        break;
    }
    lcd.setCursor(0,1);
    convertUnixToReadable( time_of_breach );

    irrecv.resume();
    while( !irrecv.decode(&results) ) { /* Wait for input! */ }
    switch(results.value)
    {
      case 0xFF22DD: printLog( current_log - 1 );    break;
      case 0xFF02FD: printLog( current_log + 1 );    break;
      case 0xFFB04F: lcd.clear(); /* If return, just let it go */ break;
      default: printLog(current_log); // Other button press or undefined
    }
    irrecv.resume();
  } else{
    lcd.clear();
    lcd.print("NO LOGS");
    delay( 1000 );

    if( current_log > 0 )
      // If current log isn't 0, send them back a log
      printLog( current_log - 1 );
  }
}
\end{lstlisting}

\section{Evaluation}

\subsection{What went right.}

Generally speaking I consider this project to be a success. All of the most important features are implemented, the device is secure, and the code and hardware layout is generally elegant. I'm reasonably proud of how we got around some of the Arduino's specific nuances in terms of timekeeping and persistent storage in EEPROM.

Our user experience does have room for improvement (it's not immediately intuitive) but it is quite fast and responsive meaning that once a user learns their way around the system, it's fairly pleasant to do so.

Viewing logs, changing the date/time, logging in, arming the system and all of the sensors work as intended with few consequences.

We were able to demonstrate that the project implemented all of its intended functionality during the lab demonstrations.

\subsection{Room to improve.}

Given time or given the opportunity to rise above some of the issues with Arduino, some improvements could be made.

The user experience is a bit complicated. Although some of the commands correlate nicely to buttons on the remote control (ON/OFF arms or disarms the alarm, MUTE silences an ongoing alarm signal, etc.) many do not (for instance command 0 is to set the user password). We should've spent time building a menu based system for options and settings.

One notable issue is that if the analog threshold is exceeded as the system is arming, the alarm will start going off immediately after the countdown has reached zero. We should warn the user about active zones before arming the system.

One feature I wished to implement but failed to build was the ability to synchronise the clock to another device using serial communication.

It would also make sense to implement setting the clock using the number pad rather than the + / - buttons alone.

Given other hardware and further time, there would be some interesting additional functionalities we could build. Using a GSM or Ethernet shield, we could make this a connected device that would interface with other devices. It'd be interesting to implement some web server functionality and allow for the viewing of logs or the administration of the device over the network. 

\section{Appendix 1: Complete Code}
Contains previously mentioned code and comments.

\begin{lstlisting}
#include <EEPROM.h>
#include <Time.h>  
#include <IRremote.h>
#include <LiquidCrystal.h>

/**
 * @author Colm Cahalane <113326986>
 * @author Evan Smith <113300626>
 *
 * Build a burglar alarm --- The task for the project 
 * was to build a device, using an arduino, that could 
 * monitor several different types of zones, log alarm
 * trips and allow for user and admin interaction via 
 * an LCD. When an alarm condition is met, a buzzer 
 * or LED will go off indicating as such.
 * 
 * Pins
 * ====
 * 
 * Digital
 * -------
 * 
 * 2 (interrupt) : Continuous Zone 
 * 3 (interrupt) : Digital Zone
 * 4 : LCD Screen 
 * 5 : LCD Screen
 * 6 : LCD Screen
 * 7 : LCD Screen
 * 8 : LCD Screen
 * 9 : LCD Screen
 * 10: Entry/Exit Zone
 * 12: IR Sensor
 * 13: ALARM
 * 
 * Analog
 * ------
 * 0 : Analog Zone 1
 *
 * IR Remote Layout
 * ----------------
 *
 * EQ : Enter password (4-Digit Pin)
 * Return : Return to standard menu
 * Play/Pause : Navigate Log
 *   Next     : Next log
 *   Prev     : Previous log
 * Mute       : Turn off alarm
 * Power      : Set/unset the alarm
 * 0  : Set user password
 * 1  : Set admin password
 * 2  : Set lower bound hour for entry/exit zone
 * 3  : Set upper bound hour for entry/exit zone
 * 4  : Set digital activate condition
 * 5  : Set analog threshold
 *
 * EEPROM Mapping
 * --------------
 * 0 - 1 : password (unsigned int)
 * 2 - 3 : admin password (unsigned int)
 * 4 - 5 : number of breaches (unsigned short)
 * 6 - 8 : first-time settings ("set" or anything else)
 *
 *  Entry/Exit (Zone 0)
 *    15     : lower-bound hour (unsigned short)
 *    16     : upper-bound hour (unsigned short)
 *
 *  Digital (Zone 1)
 *    20    : trip condition (unsigned short)
 *    
 *  Analog  (Zone 2)
 *    30 - 32 : threshold (unsigned int)
 *
 * 100 - 511 : Logging
 *   Bit Mapping (6 bytes each):
 *   0 - 3 : time (unsigned long int)
 *   4 - 5 : zone (unsigned short)
 *   
 *   
 */

#define PASSWORD              0     // 4 digit pin
#define ADMIN_PASSWORD        2     // 4 digit pin
#define NUMBER_OF_BREACHES    4
#define FIRST_TIME_SET        6

// ~~~~~ ENTRY / EXIT ZONE ~~~~~
#define ENTRY_EXIT_ZONE       0
#define ENTRY_EXIT_PIN        10
#define LOWER_TIME_BOUND      15     // Hour (2 digits max)
#define UPPER_TIME_BOUND      16     // Hour (2 digits max)

// ~~~~~~~ DIGITAL ZONE ~~~~~~~~
#define DIGITAL_ZONE          1
#define DIGITAL_CONDITION     20    // HIGH (1) or LOW (0)
#define DIGITAL_ZONE_PIN      3

 // ~~~~~~~ ANALOG ZONE ~~~~~~~~
#define ANALOG_ZONE           2
#define ANALOG_THRESHOLD      30    // short between 0 - 255
#define ANALOG_ZONE_PIN       0

 // ~~~ CONTINUOUS MON ZONE ~~~~
#define CONTINUOUS_ZONE       3
#define CONTINUOUS_ZONE_PIN   2

 // ~~~~~ TIME SETTING MODE ~~~~
#define HOUR 0
#define MINUTE 1
#define DAY 2
#define MONTH 3
#define YEAR 4

// ~~~~~~~~~ LOGS ~~~~~~~~~~~~~~
#define LOG_MEMORY_START  100
#define LOG_LENGTH        6

// ~~~~~~~~~~ IR ~~~~~~~~~~~~~~~
#define IR_RECV_PIN   12
IRrecv irrecv(IR_RECV_PIN);
decode_results results;

#define ALARM_PIN     13

// initialize the library with the numbers of the interface pins
LiquidCrystal lcd(9, 8, 7, 6, 5, 4);

// Used to check if current user is an admin
unsigned short is_admin = 0;

// 0 is disabled ; 1 is enabled
unsigned short alarm_set = 0;

// 0 alarm is idle ; 1 alarm is ringing
volatile unsigned short alarm_active = 0;

// 0 not logged in ; 1 logged in 
unsigned short is_user_logged_in = 0;

/**
 * Prints the current time to the LCD
 */
void printTime(){
  lcd.setCursor(0, 0);
  convertUnixToReadable(now());
}

/**
 * Pads and prints an integer with 0s
 * @param val Integer to pad
 */
void printWithLeadingZero(int val){
  if(val < 10){
    lcd.print('0');
  }
  lcd.print(val);
}

/**
 * Set the time
 */
void changeTime(){
    TimeElements t;
    time_t newTime;
    breakTime(now(), t);
    
    int settingsMode = 0;
    short exitLoop = 0;

    while( !exitLoop ){
      newTime = makeTime(t);
  
      lcd.clear();
      lcd.setCursor(0,0);

      lcd.print( hour(newTime) );
      lcd.print(':');
      printWithLeadingZero( minute(newTime) );

      lcd.print(' ');

      printWithLeadingZero( day(newTime) );
      lcd.print('/');
      printWithLeadingZero( month(newTime) );
      lcd.print('/');
      lcd.print( year(newTime) );

      lcd.setCursor(0,1);
      
      if(settingsMode == HOUR){
        lcd.print("Setting HOUR");
      } else if(settingsMode == MINUTE){
        lcd.print("Setting MINUTE");
      } else if(settingsMode == DAY){
        lcd.print("Setting DAY");
      } else if(settingsMode == MONTH){
        lcd.print("Setting MONTH");
      } else if(settingsMode == YEAR){
        lcd.print("Setting YEAR");
      }

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

    setTime(newTime);
}

int getDigitFromIR(){
  while( 1 ){
    irrecv.resume();
    while( !irrecv.decode(&results) ) { /* Wait for input! */ }
    switch(results.value)
    {
      case 0xFF6897: return 0;
      case 0xFF30CF: return 1;
      case 0xFF18E7: return 2;
      case 0xFF7A85: return 3;
      case 0xFF10EF: return 4;
      case 0xFF38C7: return 5;
      case 0xFF5AA5: return 6;
      case 0xFF42BD: return 7;
      case 0xFF4AB5: return 8;
      case 0xFF52AD: return 9;
      default:       break; // Other button press or undefined; reloop
    }
  }
}

/**
 * Attempt to log in a user, prompting
 *   them for a user or admin password
 * @return 1 if user logged in ; 0 otherwise
 */
int loginMode() {
  lcd.clear();
  lcd.print( "Login Mode");
  if( !is_user_logged_in || !is_admin ){
    // if admin is already logged in, bypass login

    lcd.clear();
    if( is_user_logged_in && !is_admin ){
      lcd.print( "Enter admin pin");
    } else {
      lcd.print( "4 Digit Pin");
    }
    delay(50);
    
    int pin_entered = 0;
    unsigned int password, admin_password;
    EEPROM.get( PASSWORD, password );
    EEPROM.get( ADMIN_PASSWORD, admin_password );

    lcd.setCursor(0, 1);
    for(int i = 0; i < 4; i++){
      int received_value = getDigitFromIR();      
      pin_entered *= 10;
      pin_entered += received_value;
      lcd.print('*');

      // Minor delay to prevent debouncing "0"s
      delay(50);
      irrecv.resume();
    }

    lcd.setCursor(0,1);
    if( !is_user_logged_in && pin_entered == password ){
      is_user_logged_in = 1;
      lcd.print( "LOGGED IN" );
    } else if( pin_entered == admin_password ){
      is_admin = 1;
      is_user_logged_in = 1;
      lcd.print( "LOGGED IN" );
    } else{
      lcd.print( "FAILED LOGIN" );
    }
    delay(1500);
  } else{
    lcd.print("You are admin");
  }
  lcd.clear();
  
  return is_user_logged_in;
}

/**
 * Append log to memory
 * @param time_of_breach Unix timestamp of current time
 * @param zone           Zone number that was breached
 */
void appendLog( unsigned long int time_of_breach, unsigned short zone ){

  unsigned short number_of_breaches;
  EEPROM.get( NUMBER_OF_BREACHES, number_of_breaches );

  // Increase the number of breaches
  number_of_breaches++;
  EEPROM.put( NUMBER_OF_BREACHES, number_of_breaches );

  int memory_address = LOG_MEMORY_START + (( LOG_MEMORY_START + (LOG_LENGTH * number_of_breaches) ) % 500);

  // Write our log to EEPROM
  EEPROM.put( memory_address, time_of_breach );
  memory_address += sizeof(time_of_breach);
  EEPROM.put( memory_address, (short) zone );
}

/**
 * Allows user to navigate the stored log
 * @param current_log The current log to be printed
 */
void printLog( short current_log ){
  unsigned short number_of_breaches;
  EEPROM.get( NUMBER_OF_BREACHES, number_of_breaches );

  if( current_log <= number_of_breaches && current_log != 0){
    // If we have a log to show 
    int memory_address = LOG_MEMORY_START + (( LOG_MEMORY_START + (LOG_LENGTH * current_log) ) % 500);
    
    unsigned long int time_of_breach;
    unsigned short zone;

    // Get log info
    EEPROM.get( memory_address, time_of_breach );
    memory_address += sizeof(time_of_breach);
    EEPROM.get( memory_address, zone );
    
    lcd.clear();
    switch(zone){
      case DIGITAL_ZONE:
          lcd.print( "DIGITAL ZONE");
        break;
      case ANALOG_ZONE:
          lcd.print("ANALOG ZONE");
        break;
      case CONTINUOUS_ZONE:
          lcd.print( "CONTINUOUS ZONE");
        break;
      case ENTRY_EXIT_ZONE:
          lcd.print("ENTRY/EXIT ZONE");
        break;
      default:
          lcd.print( "UNKNOWN ZONE" );
        break;
    }
    lcd.setCursor(0,1);
    convertUnixToReadable( time_of_breach );

    irrecv.resume();
    while( !irrecv.decode(&results) ) { /* Wait for input! */ }
    switch(results.value)
    {
      case 0xFF22DD: printLog( current_log - 1 );    break;
      case 0xFF02FD: printLog( current_log + 1 );    break;
      case 0xFFB04F: lcd.clear(); /* If return, just let it go */ break;
      default: printLog(current_log); // Other button press or undefined
    }
    irrecv.resume();
  } else{
    lcd.clear();
    lcd.print("NO LOGS");
    delay( 1000 );

    if( current_log > 0 )
      // If current log isn't 0, send them back a log
      printLog( current_log - 1 );
  }
}

/**
 * Prints out unix time in a human-readable format
 * @param  input_time Unix time input
 */
void convertUnixToReadable( unsigned long int input_time ){
  TimeElements full_time;
  breakTime( input_time, full_time );

  printWithLeadingZero(full_time.Hour);
  lcd.print( ":" );
  printWithLeadingZero(full_time.Minute); 
  lcd.print( " " );
  printWithLeadingZero( full_time.Day );
  lcd.print("/");
  printWithLeadingZero( full_time.Month );
  lcd.print("/");
  lcd.print( full_time.Year + 1970 );
}

/**
 * Exit admin mode
 */
void exitAdmin( ){
  is_admin = 0;
  logout( );
}

/**
 * Remove logged in status
 */
void logout( ){
  is_user_logged_in = 0;
  lcd.clear();
  lcd.print("Logged out");
  delay(700);
}

/**
 * Change whether the alarm can be active or not
 */
void toggleAlarmSet( ){
  if( !alarm_active ){
    lcd.clear();
    // We set the alarm at the end of the function to
    // avoid interrupts triggering the alarm
    unsigned short temp_alarm = !alarm_set;
    
    if( temp_alarm ){
      logout( );
      for (int i = 9; i < 10 && i >= 0; i--){
        lcd.clear();
        lcd.print(i);
        delay(1000);
      }
      lcd.clear();
      lcd.print( "ALARM SET" );
      delay(800);
    } else{
      lcd.print( "ALARM UNSET" );
      delay(800);
    }

    alarm_set = temp_alarm;
  }
}

/**
 * Change whether alarm is ringing or not
 */
void toggleAlarm( ){
  alarm_active = !alarm_active;

  lcd.clear();
  lcd.setCursor(0,1);
  if( alarm_set ){
    if( alarm_active ){
      lcd.print( "ALARM ACTIVE     " );
      digitalWrite( ALARM_PIN, HIGH );
    } else {
      lcd.print( "ALARM DEACTIVATED" );
      digitalWrite( ALARM_PIN, LOW );
      delay(1500);
      lcd.clear();
    }
  }
}

/**
 * Trip the digital zone if conditions are met
 */
void digitalZoneTrip( ){
  volatile unsigned short trip_condition;
  EEPROM.get( DIGITAL_CONDITION, trip_condition );

  if( trip_condition ){
    if( digitalRead( DIGITAL_ZONE_PIN ) == HIGH && !alarm_active && alarm_set ){
      toggleAlarm( );
      appendLog( now(), DIGITAL_ZONE );
    }
  } else {
    if( digitalRead( DIGITAL_ZONE_PIN ) == LOW && !alarm_active && alarm_set ){
      toggleAlarm( );
      appendLog( now(), DIGITAL_ZONE );
    }
  }
}

/**
 * Trip the continuous zone
 */
void contZoneTrip( ){
  toggleAlarm( );
  appendLog( now(), CONTINUOUS_ZONE );
}

/**
 * Trip the analog zone if higher than threshold
 */
void analogZoneTrip( ){
  unsigned int threshold;
  EEPROM.get( ANALOG_THRESHOLD, threshold );

  if( analogRead( ANALOG_ZONE_PIN ) > threshold && !alarm_active && alarm_set ){
    toggleAlarm( );
    appendLog( now(), ANALOG_ZONE );
    delay(200);
  }
}

/**
 * Allows users to set permanent option 
 *   values (stored in EEPROM)
 * @param option Option number from IR Remote
 */
void setOption( short option ){
  unsigned int address;
  unsigned short digits;
  switch( option ){
    case 0:
        lcd.print("PASSWORD");
        address = PASSWORD;
        digits = 4;
      break;
    case 1:
        lcd.print("ADMIN_PASSWORD");
        address = ADMIN_PASSWORD;
        digits = 4;
      break;
    case 2:
        lcd.print("LOWER TIME (Hour)");
        address = LOWER_TIME_BOUND;
        digits = 2;
      break;
    case 3:
        lcd.print("UPPER TIME (Hour)");
        address = UPPER_TIME_BOUND;
        digits = 2;
      break;
    case 4:
        lcd.print("DIGITAL COND 0/1");
        address = DIGITAL_CONDITION;
        digits = 1;
      break;
    case 5:
        lcd.print("ANALOG THRESH 1-255");
        address = ANALOG_THRESHOLD;
        digits = 3;
      break;
    default:
        return;
      break;
  }

  if( digits > 2 ){
    // If there are more than 2 digits, we'll need an int
    unsigned int final_value = 0;
    lcd.setCursor(0,1);
    for(int i = 0; i < digits; i++){
      int received_value = getDigitFromIR();
        final_value *= 10;
        final_value += received_value;
        lcd.print(received_value);
        // Minor delay to prevent debouncing "0"s
        delay(50);
        irrecv.resume();
    }
    EEPROM.put( address, final_value );
  } else {
    // If there are less than 2 digits, we can use a short
    unsigned short final_value = 0;
    lcd.setCursor(0,1);
    for(int i = 0; i < digits; i++){
      int received_value = getDigitFromIR();
        final_value *= 10;
        final_value += received_value;
        lcd.print(received_value);
        // Minor delay to prevent debouncing "0"s
        delay(50);
        irrecv.resume();
    }
    EEPROM.put( address, final_value );
  }
}

/**
 * Places default values in memory if it's the 
 * first time
 */
void defaults(){
  unsigned int password = 1234, 
               admin_password = 5678, 
               analog_threshold = 100;

  unsigned short number_breaches = 0,
                 lower_bound_hour = 20,
                 upper_bound_hour = 22,
                 digital_trip_condition = 1;

  char first_time[] = "SET";
  EEPROM.put( FIRST_TIME_SET, first_time );
  EEPROM.put( PASSWORD, password );
  EEPROM.put( ADMIN_PASSWORD, admin_password );
  EEPROM.put( ANALOG_THRESHOLD, analog_threshold );

  EEPROM.put( NUMBER_OF_BREACHES, number_breaches );
  EEPROM.put( LOWER_TIME_BOUND, lower_bound_hour );
  EEPROM.put( UPPER_TIME_BOUND, upper_bound_hour );
  EEPROM.put( DIGITAL_CONDITION, digital_trip_condition );
}

/**
 * Check if settings exist
 * @return 0 if not first time; 1 if first time
 */
int settingsSet( ){
  char first_time[3];

  EEPROM.get( FIRST_TIME_SET, first_time );

  return !(first_time == "SET");
}

void setup() {
  pinMode(ALARM_PIN, OUTPUT);
  pinMode(CONTINUOUS_ZONE_PIN, INPUT);
  pinMode(DIGITAL_ZONE_PIN, INPUT);
  pinMode(ENTRY_EXIT_PIN, INPUT);

  digitalWrite( ALARM_PIN, LOW );
  digitalWrite( CONTINUOUS_ZONE_PIN, LOW );
  digitalWrite( DIGITAL_ZONE_PIN, LOW );

  attachInterrupt( digitalPinToInterrupt(DIGITAL_ZONE_PIN), digitalZoneTrip, CHANGE  );
  attachInterrupt( digitalPinToInterrupt(CONTINUOUS_ZONE_PIN), contZoneTrip, FALLING );

  int first_time = settingsSet( );

  if( first_time ){
    defaults();
  }

  alarm_set = 0;
  
  setTime( 1447854337 );
      
  irrecv.enableIRIn(); 

  lcd.begin(16, 2);
}

void loop() {

  /**
   * Trip the Entry/Exit zone as necessary
   */
  if( digitalRead(ENTRY_EXIT_PIN) == HIGH ){
    unsigned short lower, upper, currentHour;
    EEPROM.get( LOWER_TIME_BOUND, lower );
    EEPROM.get( UPPER_TIME_BOUND, upper );
    currentHour = hour();

    lcd.clear();
    lcd.print("Plz login (EQ)");
    long start_time = millis();
    lcd.setCursor(0,1);
    while( (millis() - start_time) < 20000 ){
       
      irrecv.resume();
      delay(300);
      if(irrecv.decode(&results)){  
        if( results.value == 0xFF906F ){
          if( !is_user_logged_in ){
           loginMode( );
          }
          lcd.clear();
          lcd.print("Crisis averted");
          delay(800);
          break;
        }
      }
      lcd.clear();
      lcd.print("Plz login (EQ)");
      lcd.setCursor(0,1);
      lcd.print( 20 - ((millis() - start_time) / 1000) );
    }
    irrecv.resume(); 

    if( !alarm_active && alarm_set && !( currentHour <= lower && currentHour >= upper) ){
      // If current hour is not between the upper and lower bound
      // then activate the alarm
      toggleAlarm( );
      appendLog( now(), ENTRY_EXIT_ZONE );
      delay( 200 );
    }
  }
  
  analogZoneTrip( );

  if( irrecv.decode(&results) ) {
    switch(results.value)
    {
      case 0xFF906F: 
          // EQ
          loginMode();
        break;
      case 0xFFA25D:
          // POW
          if( !alarm_active && ( is_user_logged_in || loginMode() ) )
            toggleAlarmSet( );
        break;
      case 0xFFE21D:
          // MUTE
          if( alarm_active && ( is_user_logged_in || loginMode() ) ){
            toggleAlarm();
          }
        break;
      case 0xFFC23D: 
          /* PLAY/PAUSE */ 
          if( is_user_logged_in || loginMode() )
            printLog( 1 ); 
        break;
      case 0xFF9867:
          /* 100+ */
          if(is_user_logged_in || loginMode() ){
            changeTime();
          }
        break;

      case 0xFFB04F:
          // RET
          if( is_admin ){
            exitAdmin( );
          } else if( is_user_logged_in ){
            logout();
          }
        break;

      /* SET OPTION VALUES */
      case 0xFF6897: 
          if( is_admin || ( loginMode( ) && is_admin ) )
            setOption( 0 );
        break;
      case 0xFF30CF: 
          if( is_admin || ( loginMode( ) && is_admin ) )
            setOption( 1 );
        break;
      case 0xFF18E7: 
          if( is_admin || ( loginMode( ) && is_admin ) )
            setOption( 2 );
        break;
      case 0xFFFFFF: 
          if( is_admin || ( loginMode( ) && is_admin ) )
            setOption( 3 );
        break;
      case 0xFF10EF: 
          if( is_admin || ( loginMode( ) && is_admin ) )
            setOption( 4 );
        break;
      case 0xFF38C7: 
          if( is_admin || ( loginMode( ) && is_admin ) )
            setOption( 5 );
        break;

      default: 
    }

    irrecv.resume(); // Receive the next value
  } else {
      printTime();
  }

}
\end{lstlisting}

\section{Appendix 2: User Manual}
The RainbowTables Burglar Alarm is an arduino-based alarm system. As such, it will need to be powered by some external power source or by USB, but it will not need to be connected to a computer to function. As soon as it is powered on, it will set some default settings.

It by default monitors four zones, an entry-exit zone, a digital zone, an analog zone, and an anti-tampering device located within the alarm.

To log into the system, you can press the EQ button, and enter one of the default passwords; for basic user it's {\fontfamily{cmtt}\selectfont 1234} and for administrator it's {\fontfamily{cmtt}\selectfont 5678}.

Once you're logged in as administrator, you can change these passwords. For user password, press 0 to change. For administrator, press 1.

There are some other settings you can change from this screen. Pressing 2 allows you to set the lower bound hour for the entry-exit zone, and pressing 3 allows you to set the upper bound hour. What this means is that you can set the time during which the entry-exit zone is monitoring actively and can trigger an alarm. These bounds are set by giving a number from 0 to 24 indicating the hours at which it is active. By default, it is active from 20:00 to 22:00.

You can also set if the digital zone should be triggered on a switch to low or high. This can be changed by pressing 4. By default, it activates on High. If you wish for it to activate on Low, set this value to 0. Set this value back to 1 if you would like to restore the default behaviour.

You can also set the sensitivity of the analog zone - a number from 0 to 1024 indicating the value at which the analog zone is triggered. 0 represents no voltage being carried, and 1024 represents a 5 volt charge. You can set this value by pressing 5. By default, this value is set to 100.

To set the clock on the device, press the 100+ button. Navigate between the Day/Month/Year\-/Hour/Minute settings using the Previous and Next buttons and use the + and - buttons to adjust these values. Press the return button to save settings.

To arm the alarm system, press the power button. Note that you will be logged out and given a countdown for which to exit the area as monitoring will begin after this period.

If you trigger an alarm, you can press the mute button to silence it. You will be asked to log in if you are not already. If you trigger the Entry-Exit zone, you have a twenty second window to log in with a valid password (by pressing EQ) before the alarm becomes triggered.

When an alarm is triggered, a log is recorded of the incident. To view the logs, press the Play-Pause button. Using the Previous and Next buttons, you can navigate through a log of breaches.

To log out, simply press the return button.

If the device is powered off or plugged out, the clock will be reset but the settings and logs will remain. 

\section{Appendix 3: Project Plan}
\begin{enumerate}
    \item Review description and decide on possible hardware design
    \item Create a basic hardware design (with Fritzing) which implements each sensor zone.
    \item Ensure that the pin layout chosen fits some requirements (interrupts limitation etc.)
    \item Construct this hardware.
    \item Design a basic implementation of software that monitors and reacts to the sensor zones.
    \item Test this implementation of hardware and software.
    \item Implement and test an LCD clock on top of the alarm system.
    \item Implement and test a basic user interaction system using the IR remote on top of the above.
    \item Implement and test a user account and privileges system, allowing users to activate/deactivate the alarm, set the clock, etc.
    \item Map out locations within EEPROM where values will be stored.
    \item Implement and test integrity checking and defaults.
    \item Allow users to change these settings and store their values in EEPROM. Test this.
    \item Implement logging functionality and test.
    \item Run a complete test of all functionality.
    \item Make necessary changes to respond to any limitations or issues that arose in testing.
    \item Finalize code and design, test, and present in class.
\end{enumerate}

\end{document}

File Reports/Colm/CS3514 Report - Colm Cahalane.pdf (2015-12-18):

### CS3514 C Programming for

### Microcontrollers Report

Colm Cahalane | 28/11/2015

## Contents

1 Introduction | 2
2 Requirements\Analysis\Design | 3
3 Implementation | 6
4 Evaluation | 16
5 Appendix 1: Complete Code | 17
6 Appendix 2: User Manual | 34
7 Appendix 3: Project Plan | 35
Building a Burglar Alarm with Arduino | Page 1

## 1 Introduction

The goal of this project was to construct a burglar alarm with some basic functionality using C and

the Arduino framework for microcontrollers.

Some basic restrictions and requirements that were to be placed on the project were:

- The burglar alarm should be standalone and shouldn’t need a computer to run.
- The burglar alarm should have a settable clock with date and time.
- The burglar alarm must support multiple zones:

– A digital zone, which can be active on high or low.

– An analog zone, with a variable threshold that can be set by user.

– An entry-exit zone that allows a user to enter a PIN number and not set off the alarm -

or allow a user to arm the system and exit during a grace period.

– A continuous monitoring zone that triggers on the high → low transition.

- The burglar alarm must have a number of persistent settings stored in memory.
- The burglar alarm should have a basic PIN login system.

– There should be a separate administrator level for making settings.

- The burglar alarm should have the ability to store logs in EEPROM. A registered administrator

should be able to view these logs on screen.

We were given a basic Arduino Duemilanove kit with which to construct the project which included

an IR Remote and receiver, 2x16 character LCD Display, buttons to use as triggers, a potentiometer

for analogue input, some LED lights and buzzers, a breadboard and a collection of wires.

## 2 Requirements\Analysis\Design

### 2.1 What are we building?

As our group interpreted the project specifications, hardware-wise, we’re looking to build a device

that relays sensors for the four zones and a receiver for the IR remote to the Arduino.

The digital zones and entry-exit zones here will be activated by buttons, as that’s the most simple

implementation of such. Ideally, we’d like to have some sort of IR sensor for the entry-exit zone, but

this is complicated by our use of IR for the remote.

The Continuous Monitoring Zone behaves like a sort of anti-tamper device; it’s attached directly to a source of 5V. If the connection is broken and a high → low transition occurs on this signal, an

interrupt should be triggered in software.

In return, output is to be handled by a single-pin output for a buzzer or LED and a more detailed

output through the LCD display.

Ideally, for digital inputs, it would be best that we could implement these as triggering interrupts.

The goal of the project is that a user can interface with the alarm’s options and settings clearly

using the LCD and remote, so inputs and outputs related to operating the device should be kept

very simple.

Most of the alarm’s other functionality, such as timekeeping, permanent storage etc. can be imple-

mented purely in software.

In the below table and figure we’ll describe the hardware implementation and design we settled on

as a group.

Table 1: A list of the Arduino’s pins in use, and how we’re using them.
Pin # | Mode | Function
2 | Input (Interrupt) | Continuous Monitoring
3 | Input (Interrupt) | Digital Zone
4 | Output (LiquidCrystal) LCD
5 | Output (LiquidCrystal) LCD
6 | Output (LiquidCrystal) LCD
7 | Output (LiquidCrystal) LCD
8 | Output (LiquidCrystal) LCD
9 | Output (LiquidCrystal) LCD
10 | Input | Entry/Exit Zone
12 | Input (IRRemote) | IR Sensor
13 | Output | Alarm Output
A0 | Analog Input | Analog Zone

Figure 1: A diagram, generated using Fritzing, that shows the hardware design we decided on.

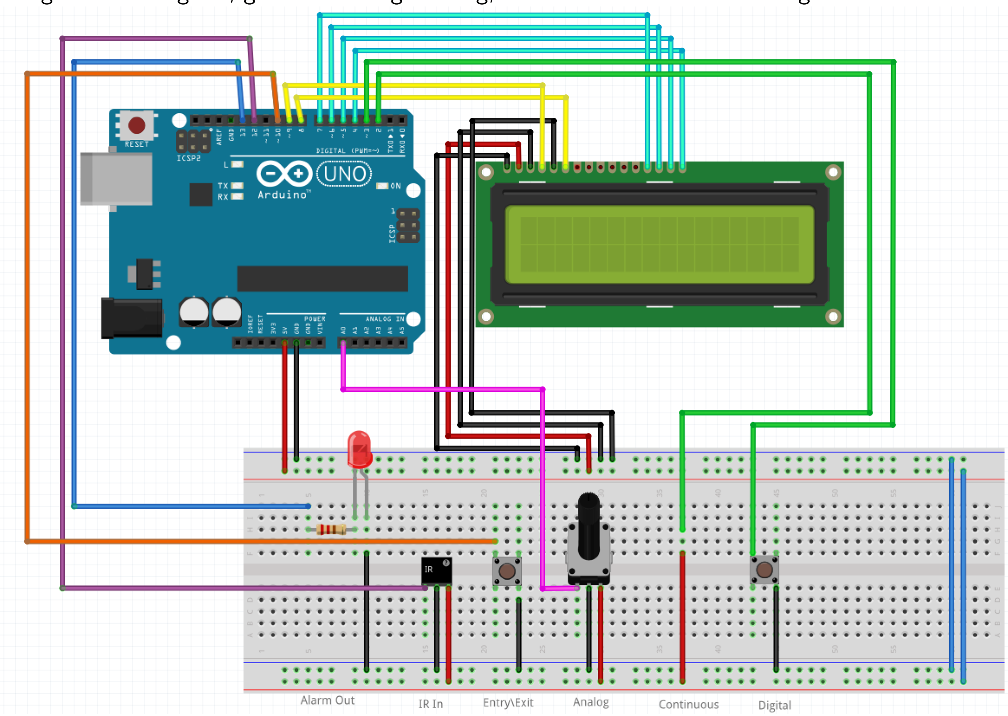
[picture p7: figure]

### 2.2 What are the features we’re building?

We’ll need to build software that monitors and responds to the aforementioned zones.

As indicated in the introduction, we’re looking to build a number of useful features on top of the

hardware that we’ve designed. We’ll need to be able to have user login and verification, two different

passwords (one for admin and one for ”normal” user).

We’ll need an implementation of a clock and allow the user to set the time. Timekeeping is important

for our implementation of the entry/exit zone as it has certain specific hours of activity each day as

well as

We’ll need a way to implement user settings and make sure that defaults are working in a way that

makes sense.

The settings that we’ll need to implement are:

- User Password
- Admin Password
- Threshold for Analog Zone (0 - 1024)
- Active Hours for Entry\Exit zone
- Digital Zone - active high or active low

We’ll need to develop a simple user privileges system and login mode to ensure that these settings

are protected. Also, we shouldn’t allow the alarm to be unset or disarmed until a valid login has

occurred.

If any of the zone conditions are triggered, an alarm should start sounding and only be disabled if

a logged-in user silences it. When an alarm sounds, we want there to be a record of this stored in

permanent storage.

We’ll also want these logs to be viewable by a logged-in user.

### 2.3 What are the limitations we’ll face?

2.3.1 16x2 Screen

The 16x2 screen, allowing for 32 characters on screen at any time and of which one row is generally

used for the clock, means that the user experience must suffer for functionality; we weren’t able to

provide for a full user menu and navigation experience. In the software design we’ve built commands

must be learnt off or read from a manual. This is less than ideal.

### 2.3.2 Timekeeping

The Arduino doesn’t have much functionality for timekeeping built in that would work in a way that

suits us. While we can keep count of the number of milliseconds since the Arduino was started

using millis(), this doesn’t work within interrupts and is not an adequate solution to implement a

settable clock.

We’d have to implement a clock ourselves through a carefully written interrupt, or we could use the

Time.h library.

### 2.3.3 Limited number of interruptable pins

Though it would suit us to have all digital inputs handled as interrupts, the Arduino Duemilanove

board only allows pins 2 and 3 to trigger interrupts. As such, we can’t attach an interrupt to each

of the digital, entry-exit and continuous monitoring zones. We must choose these carefully.

### 2.3.4 EEPROM

Permanent storage on an Arduino board is here provided by a library which allows for writing from

and reading to EEPROM storage based on addresses. It is therefore important to us to divide the

space available into EEPROM into blocks and designate specific addresses to specific functions.

We must also make sure that at the same time that we have a way of checking that the values in

EEPROM are set, and if not, imposing some defaults so that invalid information is not placed into

the program.

2.4 Dividing program into functional blocks.

Based on this description of the software, we need to start to break down the program into functional

blocks.

- A setup function that runs when the Arduino is first turned on.
- A function which runs to check if the settings stored in EEPROM are valid and if not, set

defaults.

- Interrupt service routines for when the digital or continuous zones are breached.
- The program’s main execution loop.

– A section of this loop to poll the entry-exit zone and if it has been tripped, prompts the

user to log in during a countdown - otherwise triggers alarm.

– A section of this loop to poll the analog zone and trip it if necessary

– A function allowing a user to log in/out

– A function allowing a logged in admin to view logs

– A function that displays a log at an address in EEPROM

– A function allowing a logged in admin to arm/disarm the alarm

– A function allowing a logged in user to deactivate an active alarm.

– A function allowing a logged in admin to set the time

– A function allowing a logged in admin to change options stored in EEPROM

– A function which prints the current time.

- A set of functions available to write logs to EEPROM if an alarm is triggered.
- A set of functions to allow settings in EEPROM to be read and changed.
- A set of functions to interpret user input from the IR remote and return values.

## 3 Implementation

### 3.1 Control-Flow Diagram

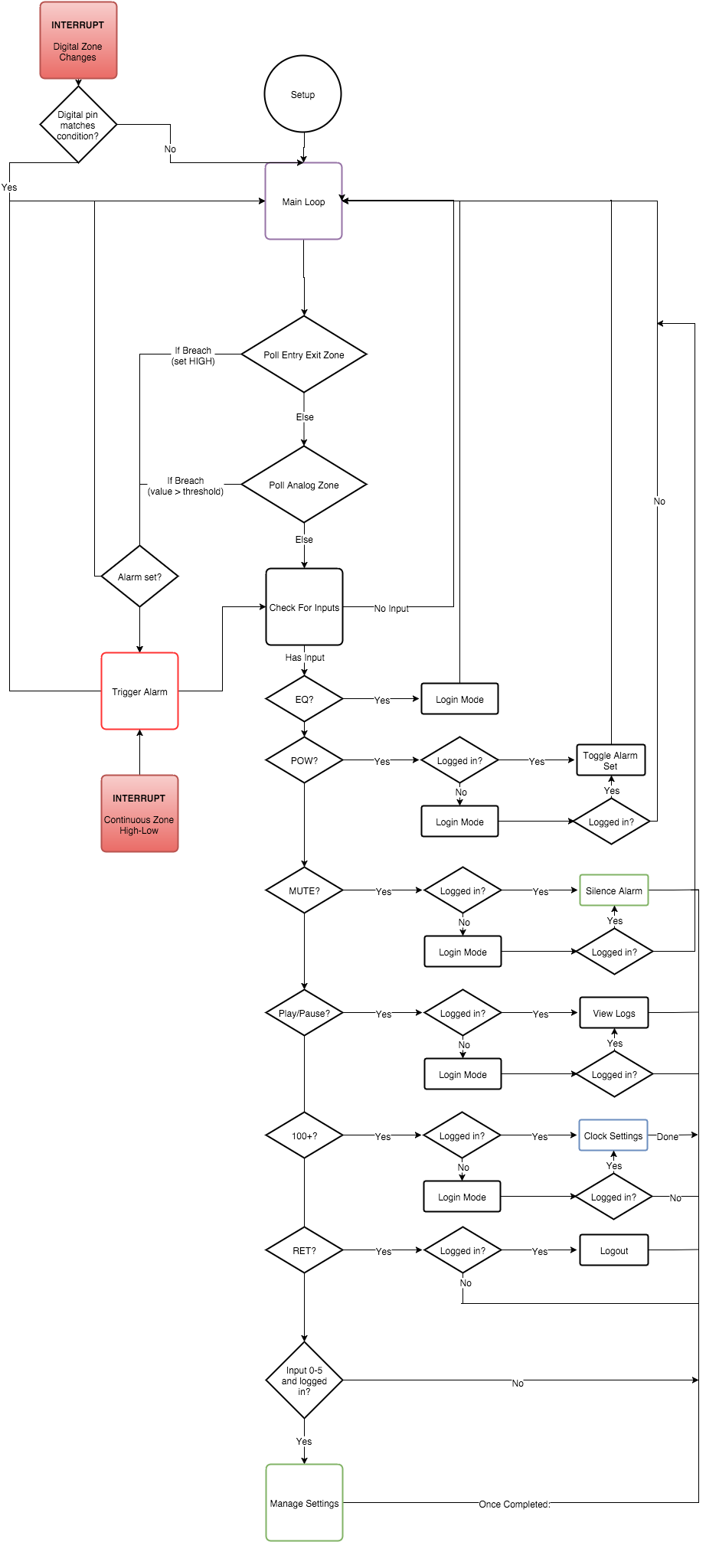
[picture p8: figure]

Figure 2: A general control-flow diagram layout for the program.

Figure 3: A control-flow diagram the program’s settings stored in EEPROM.

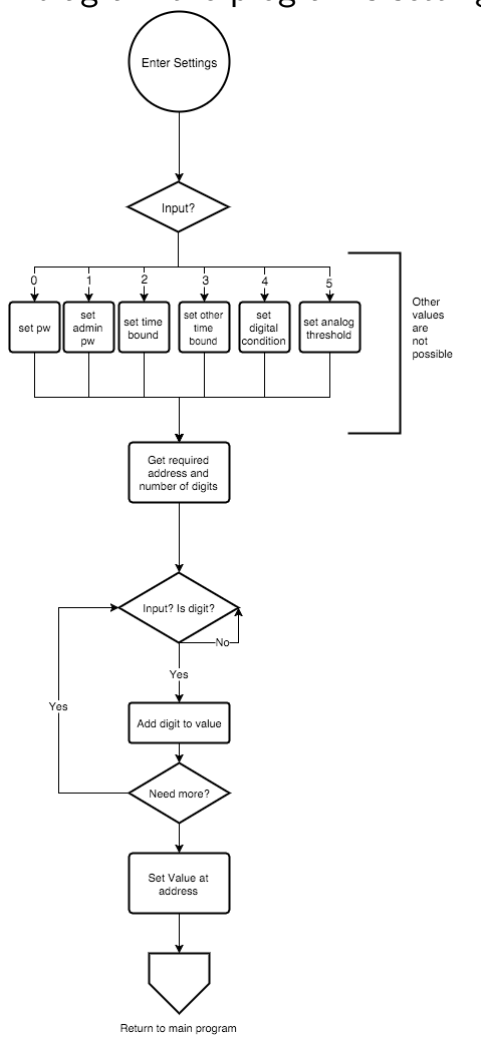
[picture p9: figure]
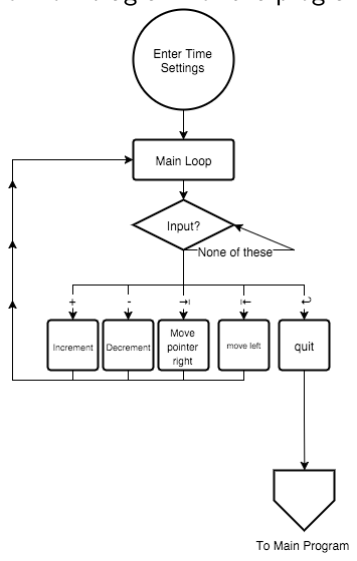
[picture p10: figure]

Figure 4: A control-flow diagram for the program’s time settings.

### 3.2 Coding Decisions

### 3.2.1 Timekeeping

As outlined above in the limitations section, we had to make a decision on using a timekeeping

library or write our own with interrupts. Our decision was to use Time.h but the limitations of the

Arduino and the small 16x2 screen meant that a user can only set the time by using the + and -

buttons to increment and decrement the day/month/hour/minute etc. rather than enter the dates

Table 2: Locations of values stored in EEPROM and their types
Location | Information | Type
0-1 | Password | unsigned int
2-3 | Administrator Password | unsigned int
4-5 | Number Of Breaches | unsigned short
6-8 | ’S’ ’E’ ’T’ values | char[]
15 | lower-bound hour for entry/exit zone | unsigned short
17 | upper-bound hour for entry/exit zone | unsigned short
20 | Trip condition for digital zone (high/low like a boolean) unsigned short
30-32 | Threshold value for analog zone | unsigned int
100-511 | Logging | 6 byte segments as follows:
L0-3 | Time of Breach | unsigned long
L4-5 | Zone ID | unsigned short

with numeric keys. Still, it makes up for this by giving us a universal date format that we can use in

creating/storing logs, and the TimeElements structure for printing/setting time with very readable

and maintainable code.

If we were to use the interrupt-based approach, this code would have been used to create a clock-

based interrupt which would trigger once per second:

1 | TCCR1A = 0;
2 | TCCR1B = 0;
3 | OCR1A = 15625;
4 | TCCR1B |= (1 << WGM12 ) ;
5 | TCCR1B |= (1 << CS10 ) ;
6 | TCCR1B |= (1 << CS12 ) ;
7 | TIMSK1 |= (1 << OCIE1A ) ;
8 | sei () ;

### 3.2.2 EEPROM Mapping and defaults

We had to map out specific areas of EEPROM and the types of values that could be stored there but

it took us a while to come up with a good solution for the first-boot and ensuring that the values

in EEPROM were legitimate. We decided on mapping a sequence of addresses that would contain

the values ’S’, ’E’, ’T’, allowing us to have a pretty reliable indicator for if the device had been set

up with the burglar alarm before. If the SET values aren’t present, we’d run a function which would

flash defaults.

### 3.2.3 User Interaction

As shown in the Control-Flow Diagram, the user can log in to the device, and then enter a number

of settings modes from within the main loop. If the user is not logged in and attempts to enter a

settings mode, they will be first asked to log in.

Handling most of this user interaction from within the main loop and not constructing an additional

menu simply means that we can continue to monitor the analog and entry-exit zones actively as the

user interacts with the device.

### 3.2.4 Interrupts

We use both interrupt pins to the board to ensure that active monitoring takes place at all times on certain pins. The continuous zone is set to interrupt on the high → low transition and instantly

triggers the alarm. The digital zone is set to interrupt on any change and if the alarm is set, is not

currently active and the digital zone switches to the condition specified by the user, the alarm is

triggered.

We can not set an interrupt-based system to monitor the analog pin, and the entry-exit zone works

better as a non-interrupt due to its tie-ins with the user account system and user interaction functions.

### 3.3 Interesting pieces of code

Here I’m including some particular segments of the codebase for the project that I find rather

interesting or valuable in achieving elements of the project specification. Of course, the complete

codebase for the project is available in the appendixes.

### 3.3.1 Getting a digit value from the IR sensor

int getDigitFromIR () {

while ( 1 ) { // Loop until a button press is received

irrecv . resume () ;

while ( ! irrecv . decode (& results ) ) { /* Wait for input ! */ }

switch ( results . value )
{

case 0 xFF6897 : return 0;

case 0 xFF30CF : return 1;

case 0 xFF18E7 : return 2;

case 0 xFF7A85 : return 3;

case 0 xFF10EF : return 4;

case 0 xFF38C7 : return 5;

case 0 xFF5AA5 : return 6;

case 0 xFF42BD : return 7;

case 0 xFF4AB5 : return 8;

case 0 xFF52AD : return 9;

17 | default : | break ; // Other button press or undefined ; reloop
}
}
}

### 3.3.2 Checking if the EEPROM is set up right and setting defaults

int settingsSet ( ) {

char first_time [3];

EEPROM . get ( FIRST_TIME_SET , first_time ) ;

// Check if the values found match our chosen string .

return !( first_time == "SET ") ;
}

void defaults () {

unsigned int password = 1234 ,

admin_password = 5678 ,

analog_threshold = 100;

unsigned short number_breaches = 0 ,

lower_bound_hour = 20 ,

upper_bound_hour = 22 ,

digital_trip_condition = 1;

char first_time [] = "SET ";

// Store our default values in memory .

EEPROM . put ( FIRST_TIME_SET , first_time ) ;

EEPROM . put ( PASSWORD , password ) ;

EEPROM . put ( ADMIN_PASSWORD , admin_password ) ;

EEPROM . put ( ANALOG_THRESHOLD , analog_threshold ) ;

EEPROM . put ( NUMBER_OF_BREACHES , number_breaches ) ;

EEPROM . put ( LOWER_TIME_BOUND , lower_bound_hour ) ;

EEPROM . put ( UPPER_TIME_BOUND , upper_bound_hour ) ;

EEPROM . put ( DIGITAL_CONDITION , digital_trip_condition ) ; }

### 3.3.3 Printing UNIX time values

void printWithLeadingZero (int val ) {

if( val < 10) {

3 | lcd . print (’0’) ;
4 | }
5 | lcd . print ( val ) ;
6 | }
7
8 | void convertUnixToReadable ( unsigned long int input_time ) {
9 | TimeElements full_time ;
10 | breakTime ( input_time , full_time ) ;
11
12 | printWithLeadingZero ( full_time . Hour ) ;
13 | lcd . print ( ":" ) ;
14 | printWithLeadingZero ( full_time . Minute ) ;
15 | lcd . print ( " " ) ;
16 | printWithLeadingZero ( full_time . Day ) ;
17 | lcd . print ("/") ;
18 | printWithLeadingZero ( full_time . Month ) ;
19 | lcd . print ("/") ;
20 | lcd . print ( full_time . Year + 1970 ) ;
21 | }

### 3.3.4 User interface for modifying time

1 | void changeTime () {
2 | TimeElements t ;
3 | time_t newTime ;
4 | breakTime ( now () , t ) ;
5
6 | int settingsMode = 0;
7 | short exitLoop = 0;
8
9 | while ( ! exitLoop ) {
10 | newTime = makeTime ( t ) ;
11
12 | lcd. clear () ;
13 | lcd. setCursor (0 ,0) ;
14
15 | convertUnixToReadable ( newTime ) ;
16
17 | lcd. setCursor (0 ,1) ;
18
19 | if( settingsMode == HOUR ) {
20 | lcd. print (" Setting HOUR ") ;
21 | } else if( settingsMode == MINUTE ) {
22 | lcd. print (" Setting MINUTE ") ;
23 | } else if( settingsMode == DAY ) {

lcd. print (" Setting DAY") ;

} else if( settingsMode == MONTH ) {

lcd. print (" Setting MONTH ") ;

} else if( settingsMode == YEAR ) {

lcd. print (" Setting YEAR ") ;
}

irrecv . resume () ;

while ( ! irrecv . decode (& results ) ) { /* Wait for input ! */ }

switch ( results . value ) {

// +4 should be -1 , but here we avoid

nevative modulo
case 0 xFF22DD : /* PREV */ settingsMode = ( settingsMode +4) %5;

break ;
case 0 xFF02FD : /* NEXT */ settingsMode = ( settingsMode +1) %5;

break ;
37 | case 0 xFFE01F : /* | - | */

if( settingsMode == HOUR ) {

| t . Hour - -;

} else if( settingsMode == MINUTE ) {

| t . Minute - -;

} else if( settingsMode == DAY ) {

| t . Day - -;

} else if( settingsMode == MONTH ) {

| t . Month - -;

} else if( settingsMode == YEAR ) {

| t . Year - -;
| }
| break ;
50 | case 0 xFFA857 : /* | + | */

if( settingsMode == HOUR ) {

| t . Hour ++;

} else if( settingsMode == MINUTE ) {

| t . Minute ++;

} else if( settingsMode == DAY ) {

| t . Day ++;

} else if( settingsMode == MONTH ) {

| t . Month ++;

} else if( settingsMode == YEAR ) {

| t . Year ++;
| }
| break ;

case 0 xFFB04F : /* RET */ exitLoop = 1; lcd . clear () ; break ; }
}

setTime ( newTime ) ;

}

### 3.3.5 Logging functions

/**

* Append log to memory

* @param time_of_breach Unix timestamp of current time

4 | * @param zone | Zone number that was breached
| */

void appendLog ( unsigned long int time_of_breach , unsigned short zone )
| {

unsigned short number_of_breaches ;

EEPROM . get ( NUMBER_OF_BREACHES , number_of_breaches ) ;

// Increase the number of breaches

number_of_breaches ++;

EEPROM . put ( NUMBER_OF_BREACHES , number_of_breaches ) ;

int memory_address = LOG_MEMORY_START + (( LOG_MEMORY_START + (

LOG_LENGTH * number_of_breaches ) ) % 500) ;

// Write our log to EEPROM

EEPROM . put ( memory_address , time_of_breach ) ;

memory_address += sizeof ( time_of_breach ) ;

EEPROM . put ( memory_address , ( short ) zone ) ; }

/**

* Allows user to navigate the stored log

* @param current_log The current log to be printed */

void printLog ( short current_log ) {

unsigned short number_of_breaches ;

EEPROM . get ( NUMBER_OF_BREACHES , number_of_breaches ) ;

if( current_log <= number_of_breaches && current_log != 0) {

// If we have a log to show

int memory_address = LOG_MEMORY_START + (( LOG_MEMORY_START + (

LOG_LENGTH * current_log ) ) % 500) ;

unsigned long int time_of_breach ;

unsigned short zone ;

// Get log info

EEPROM . get ( memory_address , time_of_breach ) ;

memory_address += sizeof ( time_of_breach ) ;

EEPROM . get ( memory_address , zone ) ;

lcd . clear () ;

switch ( zone ) {

case DIGITAL_ZONE :

lcd. print ( " DIGITAL ZONE ") ;

break ;

case ANALOG_ZONE :

lcd. print (" ANALOG ZONE ") ;

break ;

case CONTINUOUS_ZONE :

lcd. print ( " CONTINUOUS ZONE ") ;

break ;

case ENTRY_EXIT_ZONE :

lcd. print (" ENTRY / EXIT ZONE ") ;

break ;

default :

lcd. print ( " UNKNOWN ZONE " ) ;

break ;
}

lcd . setCursor (0 ,1) ;

convertUnixToReadable ( time_of_breach ) ;

irrecv . resume () ;

while ( ! irrecv . decode (& results ) ) { /* Wait for input ! */ }

switch ( results . value )
{
68 | case 0 xFF22DD : printLog ( current_log - 1 ) ; | break ;
69 | case 0 xFF02FD : printLog ( current_log + 1 ) ; | break ;

case 0 xFFB04F : lcd . clear () ; /* If return , just let it go */ break

| ;
default : printLog ( current_log ) ; // Other button press or
| undefined
}
| irrecv . resume () ;
| } else {
| lcd . clear () ;
| lcd . print ("NO LOGS ") ;
| delay ( 1000 ) ;

if( current_log > 0 )

// If current log isn ’t 0 , send them back a log

printLog ( current_log - 1 ) ;
}
}
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

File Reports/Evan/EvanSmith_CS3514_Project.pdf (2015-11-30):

# CS3514 - Burglar Alarm Project

### Evan Smith <113300626> and Colm Cahalane

19/11/2015

## Contents

1 Introduction | 2
2 Requirements / Analysis / Design | 2
3 Implementation | 3
4 Evaluation | 8
5 Appendices | 9
6 Code | 13

1

## 1 Introduction

Build a burglar alarm — The task for the project was to build a device, using an arduino,

that could monitor several different types of zones, log alarm trips and allow for user and admin

interaction via an LCD. When an alarm condition is met, a buzzer or LED will go off indicating

as such.

## 2 Requirements / Analysis / Design

### 2.1 Limitations

- 512MB permanent memory for logging and settings storage
- Only the admin is allowed to change settings
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

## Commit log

2015-11-13 Initial pin mapping
2015-11-13 Remote button mapping
2015-11-13 Mute button to silence alarm
2015-11-13 Shortcut through login if already logged in
    [Burglar_Alarm.ino]
2015-11-14 Adjust to volatile variables for interrupts
2015-11-14 Entry\Exit pin moves to loop
2015-11-15 Wrong value for 3
    [Burglar_Alarm.ino]
2015-11-15 Fixed logic condition for bypassing login
    [Burglar_Alarm.ino]
2015-11-15 Remove print time as interrupt
2015-11-15 Commented out interrupt-related code
2015-11-16 Updated button mappings
2015-11-16 Print log function
2015-11-16 Print log in human readable form
2015-11-16 Slightly too long for the lcd screen
    [Burglar_Alarm.ino]
2015-11-18 Shorts are actually 2 bytes in arduino
    [Burglar_Alarm.ino]
2015-11-19 Initial Control-Flow Diagram
    This excludes the numeric buttons on the remote as a starting point
2015-11-19 Added remote buttons to diagram
2015-11-19 Control Flow Diagrams
2015-11-20 Separated control flow diagrams
2015-11-23 Log fixes and timer added to entry/exit zone
    [Burglar_Alarm.ino]
2015-11-30 Evan's finished report
    [CircuitDiagram.fzz, CircuitDiagram_old.fzz]
